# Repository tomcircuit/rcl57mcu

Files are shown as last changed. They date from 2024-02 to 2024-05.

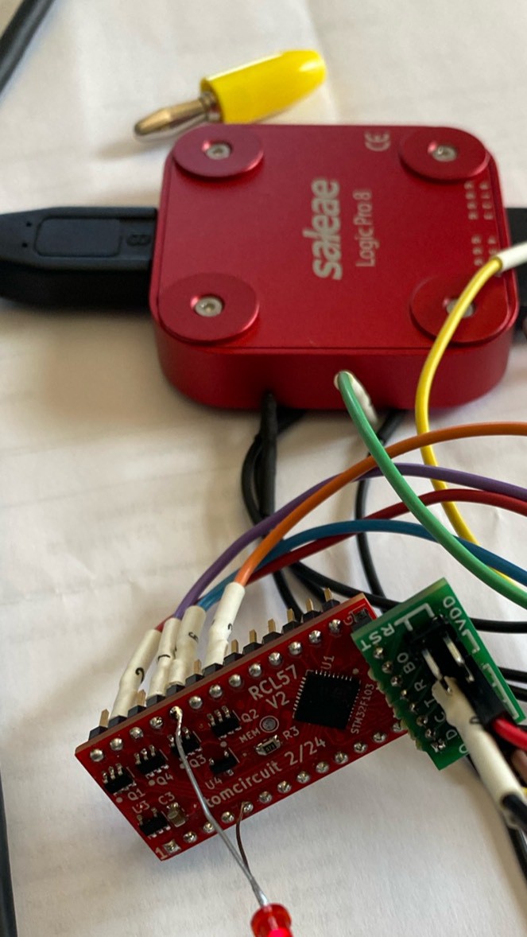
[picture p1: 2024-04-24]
media/assembled debug.jpg

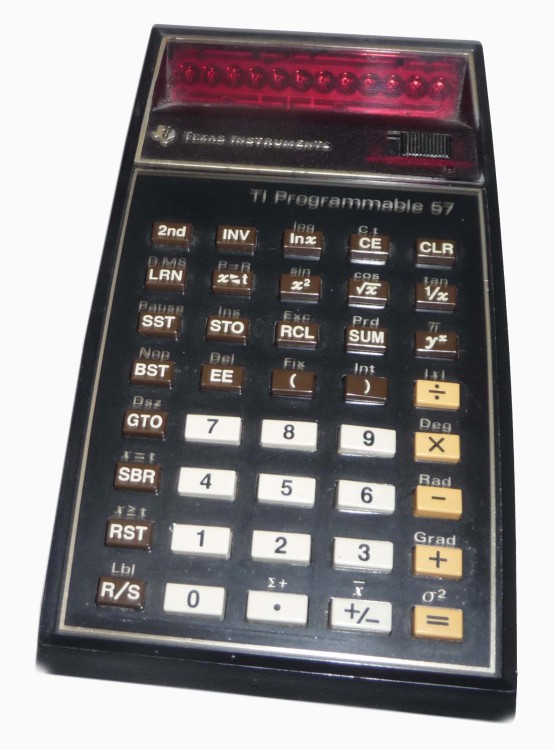
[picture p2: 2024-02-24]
media/ti57_image_uk_computing_history_museum.jpg

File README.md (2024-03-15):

# rcl57mcu

## MCU-based retrofit for TI-57 Programmable Calculators

This project came about because I stumbled across a TI-57 calculator with a "bad brain". The TMC1501 calculator-on-a-chip was faulty. This, in turn, led me to read more about this particular calculator and how the CPU inside functions. 

Fortunately, I am 'standing on the shoulders of giants' here - three people that have been of great help to me are Joerg Woerner, Jeff Parsons and Paul Novaes. All have humored me by answering my emails and helping me understand how the hardware works. 

Joerg's DATAMATH pages are amazing reading, and in particular there is an excellent [overview of the TMC1501 calculator-on-a-chip IC](http://www.datamath.org/Chips/TMC1500.htm) used in the TI-57.

Jeff Parsons' TI-57 pages include an online emulator and lots of history on TI-57 development. Extremely helpful is his [collection and analysis of original Texas Instruments patents](https://www.pcjs.org/machines/ti/ti57/patents/) filed around the introduction of this calculator.

Both Jeff and Paul have created TI-57 emulators. Paul's is an iOS app, and Jeff's is browser-based. Both emulate the TMC1501 CPU innards, which in turn execute the original TI-57 ROM code. So it is a faithful 'emulation'.

Paul was kind enough to put his [iOS app code](https://github.com/n3times/rcl57) up on GitHub

The 'guts' of the TMC1500 emulation are all contained within the 'engine' folder, and written in very generic and portable C. I learned an awful lot from studying this code.

## The Quest

I began to hatch a scheme - could I put a modern microcontroller (MCU) to the task of emulating the 1970's TMC1501? Could this hardware emulator be then installed into my defunct TI-57 to make it live again, perhaps even better than before?

See the hackaday page for more info on this project: 

https://hackaday.io/project/194963-ti-57-programmable-calculator-hardware-retrofit

Tom LeMense
February 2024

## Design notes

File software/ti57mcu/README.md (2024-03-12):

# RCL57mcu - TI-57 emulator on an MCU

* Author: Tom LeMense 
* Toolchain: Keil uVision/MDK
* Target: STM32F103TB (CM3, 128K Flash, 20K RAM)
* Hardware: rcl57mcu PCB V2
* Repository: [github.com/tomcircuit/rcl57mcu](https://github.com/tomcircuit/rcl57mcu)
* Project Webpage: [hackaday.io/project/194963](https://hackaday.io/project/194963)

Rcl57mcu was inspired by the work of Jeff Parsons and Paul Novaes, from whose work developoing PC and iOS emulators I was able to study and then eventually develop a microcontroller-based TI-57 emulator. Also invaluable to me is the DATAMATH website, carefully maintained by Joerg Woerner, which contains a trove of information on all things TI calculator, but more specifically on [the TMC1501 IC inside the TI-57](http://www.datamath.org/Chips/TMC1500.htm). The rcl57mcu embedded software is more a less an embedded 'wrapper' around the "TI57 Engine" by Paul Novaes, which can be found in this repository: [github.com/n3times/rcl57](https://github.com/n3times/rcl57). 

Rcl57mcu is a hardware "drop-in" replacement for TI-57 TMC1500 DIP-28, and brings a few enhancements over the original:
 
- Calculation at 4x the speed of the original TI-57 
	+ display timing and PAUSE are same as original
- Non-volatile storage/retrieval of up to 20 user programs
- A "power save" mode if the keyboard is left idle
- USB micro-B rechargeable 3.7V LiPo battery 
- (tbc) Lower overall energy consumption

In theory, rcl57mcu could be used as speedup/retrofit in TI-55 and TI-42/"MBA" calculators, as they use the same TMC1500 IC. Of course, the correct ROM image would need to be used. I do not have these calculators, so I cannot say as to whether or not this actually works...

As part of the debugging activies, I used the "USART_Utilities" package from Saeid Yazdani, which I found at the following website [www.embedonix.com](http://www.embedonix.com) 

RCL57mcu hardware was designed by me, using the wonderful KiCAD 7.0 toolchain. Design files can be found at the GitHub repository.

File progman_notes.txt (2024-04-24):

 From TI patent, the ORDER of the segment activation
 7,6,5,2,4,0,1,3
 (don't really care about this so much I don't think)
 
Segment numbering:
E, F, B, G, C, A, D, P
0  1  2  3  4  5  6  7  (WVU)

This makes the keyboard mapping sane, also, as the segment # is then the row #

   1  1  1        
   2  1  0  9  8  7  6  5  4  3  2  1
   
      L. #  #     C  C  C  C         	These are the "library" flash programs   21-99
   
      U. #  #     C  C  C  C				These are the "user" EEPROM programs   01-20

		 ## is program number
		 CCCC is CRC-16 of program (or "- - - -" if blank)

+ increase #
- decrease #	  
STO store program in slot # if it's a USER slot (1-20)
RCL recall program from slot #
GTO goto L.21
RST goto U.01
CE clear program in slot # if it's a USER slot (1-20)
R/S exit program manager

Keep the same 50us tick:

Enter with slot = 01

generate_display_data

display_cycle

check_keyboard_input

10-100KHz
100us to 10us
DATA 0 ---> MARK/SPACE
DATA 1 ---> SPACE/MARK
MAK == DATA 1
NoMAK == DATA 0
SAK == DATA 1
NoSAK = CV (MARK-MARK)

STANDBY PULSE (TSTBY #9) = HIGH for 600us minimum (!!!)
START HEADER SETUP TIME (TSS #10) = 10us minimum (can do this instead of STANDBY pulse)
START HEADER LOW PULSE TIME (THDR #11) = 5us minimum (follows standby/header pulse)

START HEADER = 0x55 + MAK 

MEMIO high for TSS, then MEMIO low for THDR, then 0x55, then MAK, then NoSAK (don't check SAK)

24MHz clock to APB1
TIM3 :

RCC->APB1ENR |= RCC_APB1ENR_TIM3EN

TIM3->PSC = 24-1; // 24MHz APB1 divide-by-24 = 1MHz = 1us per tick
TIM3->ARR = ticks-1;  // number of ticks to count up
TIM3->EGR = 0x0001;   // update event
TIM3->CR1 = 0x0009;	 // enable counting     but also set: OPM (b3 = 1 to count only once), 

NVIC->ISER[TIM3_IRQn >> 0x05] = (uint32_t)0x01 << (TIM3_IRQn & (uint8_t)0x1f); enable interrupts
TIM3->DIER = 0x0001; enable interrupts

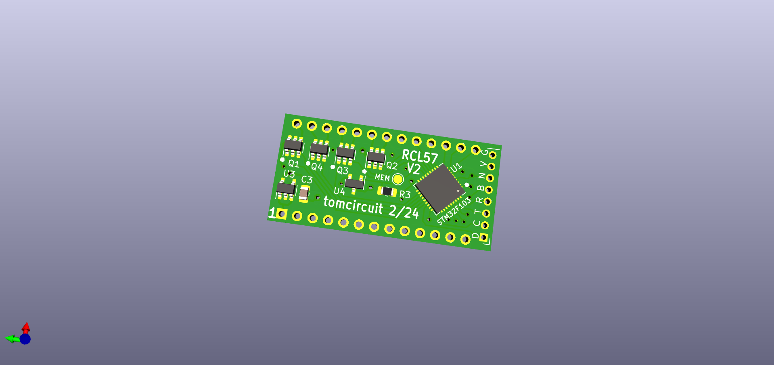
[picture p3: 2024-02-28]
hardware/rcl57_mcu/release/fab02/ti57mcu_v2_top3d.png

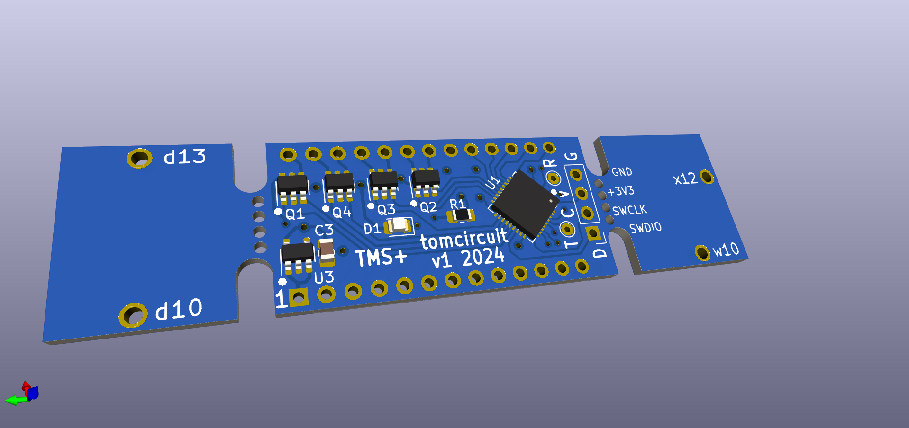
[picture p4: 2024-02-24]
hardware/rcl57_mcu/release/fab01/ti57mcu_top3d.png

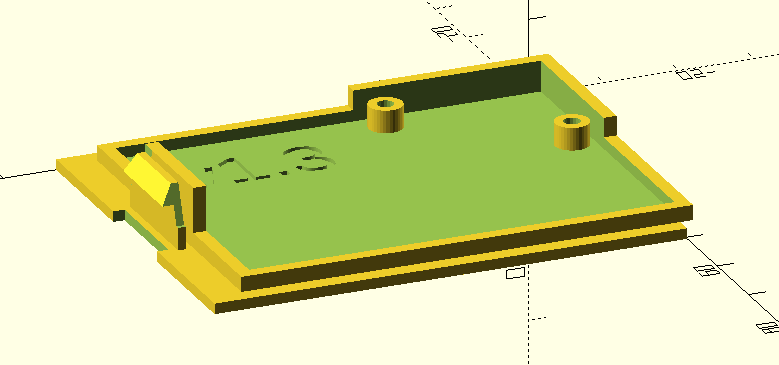
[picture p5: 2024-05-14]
mechanical/TI-57_LiPo_lid_1v3.png

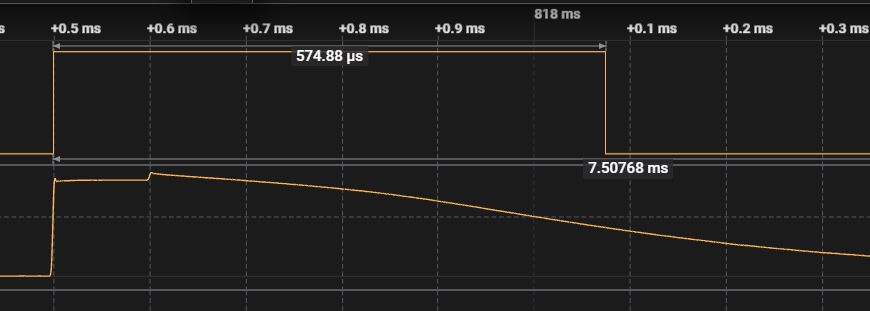
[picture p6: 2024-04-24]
media/short_segment_pulse.png

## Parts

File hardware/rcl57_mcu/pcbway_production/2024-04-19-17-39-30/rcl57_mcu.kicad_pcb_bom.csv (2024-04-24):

designator | quantity | value | pack | mpn | mount_type
C1, C2, C4, C5 | 4 | 100nF | C_0805_2012Metric |  | smt
C3, C6 | 2 | 4.7uF | C_0805_2012Metric |  | smt
J1 | 1 | TMC1500 p1-13 | PinHeader_1x13_P2.54mm_Vertical |  | tht
J2 | 1 | TMC1500 p28-16 | PinHeader_1x13_P2.54mm_Vertical |  | tht
J3 | 1 | STLINK | PinHeader_1x08_P2.00mm_Vertical |  | tht
Q1, Q2, Q3, Q4 | 4 | DMP2240UDM-7 | SOT-23-6 |  | smt
R1 | 1 | 2K | R_0805_2012Metric_Pad1.20x1.40mm_HandSolder |  | smt
R3 | 1 | 47K | R_0805_2012Metric_Pad1.20x1.40mm_HandSolder |  | smt
R4 | 1 | 330 | R_0805_2012Metric_Pad1.20x1.40mm_HandSolder |  | smt
RN1 | 1 | YC158TJR-072KL | R_Array_Convex_5x0603 |  | smt
U1 | 1 | STM32F103TBUx | QFN-36-1EP_6x6mm_P0.5mm_EP4.1x4.1mm |  | smt
U2 | 1 | TLC5929PWP | TSSOP-24-1EP_4.4x7.8mm_P0.65mm_EP3.2x5mm |  | smt
U3 | 1 | TLV70033_SOT23-5 | SOT-23-5 |  | smt
U4 | 1 | 11AA080/TT | SOT-23 |  | smt

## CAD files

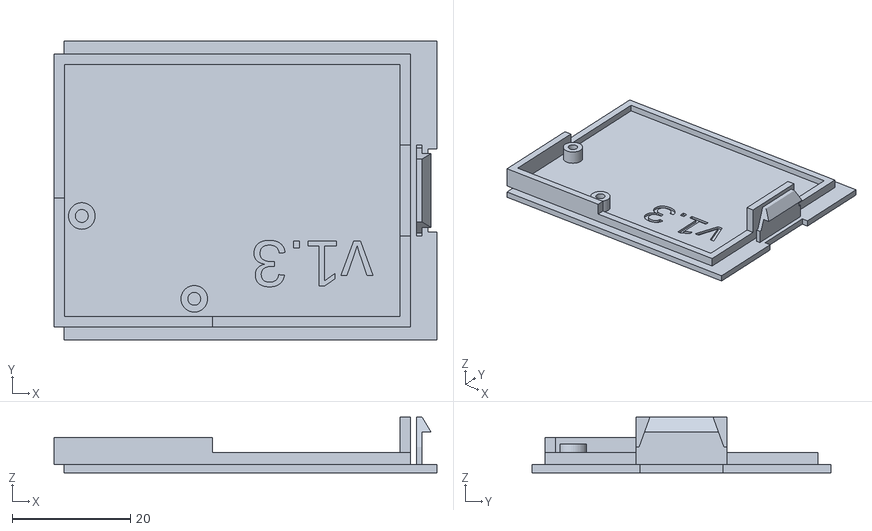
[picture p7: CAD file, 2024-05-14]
mechanical/TI-57_LiPo_lid_1v3.stl
64.7 x 50.5 x 9.40

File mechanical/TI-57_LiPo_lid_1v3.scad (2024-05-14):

/*
  TI-57 Battery Lid for LiPo Pack V1.3
  This is intended to hold a PCB and a LiPo battery for RCL-57.

  Dimensions measured from a TI-57 and a TI-55 calculator, and several BP-7 packs.
  
  1.0 - high-walls - awful latch geometry
  1.1 - high-walls - still bad latch geometery
  1.2 - ref'd off of thingiverse "Majestic_line_battery_cover.stl" file - better...
  1.3 - increased latch tab Z, decreased latch spring wall thickness - much better!

  T. LeMense
  May 13, 2024
*/


$fa = 1;
$fs = 0.4;

// W is width, and is along X AXIS
// L is length, and is along Y AXIS
// H is height, and is along Z AXIS
// T is thickness, and is along either X or Y AXIS 

// baseplate (first surface)
base_w = 63;  
base_l = 50.5;   
base_h = 1.4;  

/*
// Majestic Line Battery Cover reference STL
translate([base_w/2,base_l/2,0])
rotate([0,0,270])
import("C:/Users/lemenset/Personal/TI57_upgrade/mechanical/Majestic_line_Battery_cover.stl");
//*/

// "ledges" are setbacks around perimeter of base
ledge_long_edge = 2.2;  // ledge along long sides (estimated)
ledge_short_edge = 1.7; // ledge step-back along non-latch short end
latch_setback = 3.5;  // setback of latch (measured)
ledge_latch_edge = 4.5;  // setback of latch-side wall (measured)

// "superstructure" box - around entire cavity
super_w = base_w - ledge_latch_edge + ledge_short_edge; // width (long edge)
super_l = base_l - ledge_long_edge - ledge_long_edge;  // length (short edge)
super_h = 2;        // height of superstructure box
super_wall_t = 1.75;     // superstructure wall thickness
super_floor_add_h = 0.5; // additional floor thickness

echo("superstructure inside width is", super_w-2*super_wall_t);
echo("superstructure inside length is", super_l-2*super_wall_t);

// PCB information
pcb_l = 25;
pcb_w = 20;
pcb_t = 1.6;
pcb_hole_from_edge = 3;

// PCB position w.r.t. lid
pcb_x = 0;
pcb_y = ledge_long_edge + super_wall_t;
pcb_comp_z = 6; 
pcb_solder_z = pcb_comp_z-pcb_t-base_h;

// latch 'tab' is an extruded 2D polygon
latch_tab_w1 = 2.5; // "thickest" part of latch feature
latch_tab_h = 2.5;  // "height" of latch tab
latch_tab_w2 = 1;   // "thinnest" part of latch tab
latch_tab_l = 16.0; // "length" of latch tab
latch_tab_z = 5.5;   // relative to base_h

// construct latch tab polygon point set
p0 = [0, 0];
p1 = [0, latch_tab_h];
p2 = [latch_tab_w2,latch_tab_h];
p3 = [latch_tab_w1,0];
tab_points = [p0, p1, p2, p3];

// hinge cutout is extruded 2D polygon
cutout_l = 10.0;
cutout_h = latch_tab_z;

// built hinge cutout polygon point set
p4 = [0, 0];
p5 = [0, cutout_h];
p6 = [(latch_tab_l - cutout_l)/2,cutout_h];
p7 = [latch_tab_w2,0];
cutout_points = [p4, p5, p6, p7];

module RoundedBoss(side,height,hole_dia){
    difference() {
        translate([0,0,0])
        cylinder(d=side,h=height);
        
        translate([0,0,height/3])
        cylinder(d=hole_dia,h=height/1.5);
    }
}

function RoundedBossHoleCenter(side,height,hole_dia) = [side/2,side/2,0];   

//location of the PCB mounting bosses
boss_l = 4.5;
boss_h_dia = 2.2;
boss_inset = (boss_l - boss_h_dia)/4;
h1 = [pcb_x+pcb_hole_from_edge,pcb_y+pcb_w-pcb_hole_from_edge,0];
h2 = h1 + [pcb_l-2*pcb_hole_from_edge,-pcb_w+2*pcb_hole_from_edge,0];

// build the lid using additive and subtractive items
union(){
    difference() {
        union() {        
        // additive items        
            
        // the baseplate
        cube(size=[base_w, base_l, base_h]);
            
        // the superstructure volume
        translate([-ledge_short_edge, ledge_long_edge, base_h])
            cube([super_w, super_l,super_h]); 
        
        // the PCB box volume
        translate([-ledge_short_edge, ledge_long_edge, base_h])
            cube([super_wall_t+pcb_l,super_wall_t+pcb_w,pcb_comp_z-base_h]);
    
        // the locking tab
        translate([base_w - latch_setback,ledge_long_edge+(super_l/2)+(latch_tab_l/2),latch_tab_z+base_h]) 
            rotate([90,0,0]) 
                linear_extrude(height=latch_tab_l) polygon(tab_points);
    
        // the locking tab spring wall
        translate([base_w - latch_setback,ledge_long_edge+(super_l/3),base_h])
            cube([1, super_l/3, latch_tab_z]);
        
        // the locking tab "backstop"
        translate([base_w - ledge_latch_edge-super_wall_t,ledge_long_edge+(super_l/3),base_h])
            cube([super_wall_t,super_l/3, latch_tab_z+latch_tab_h]);
    
        } //union
        
        // subtractive items                    
        // remove tab release slot from base
        translate([base_w - 1.5,(base_l/2)-((latch_tab_l-2)/2),-0.25]) 
            cube([2.5,(latch_tab_l-2),2]);
            
        // remove the two hinge cutouts
        translate([base_w-ledge_latch_edge,ledge_long_edge+(super_l/2)-(latch_tab_l/2)-0.15,base_h+3])
            rotate([90,0,90])
                linear_extrude(height=3*super_wall_t)
                    polygon(cutout_points);
        
        translate([super_w+ledge_latch_edge,ledge_long_edge+(super_l/2)+(latch_tab_l/2)+0.15,base_h+3])
            rotate([90,0,-90]) 
                linear_extrude(height=3*super_wall_t) 
                    polygon(cutout_points);        
    
        // flatten the rounded wall edges
        translate([-2, 1.25+super_wall_t, base_h+12.5])
            cube([5,super_l-2*super_wall_t,5]);
        translate([base_w-4, 1.25+super_wall_t, base_h+10])
            cube([5,super_l-2*super_wall_t,5]);
    
        // remove the superstructure insides
        translate([super_wall_t-ledge_short_edge, ledge_long_edge+super_wall_t, base_h+super_floor_add_h])
            cube([super_w-2*super_wall_t, super_l-2*super_wall_t, 20]); 
        
        // etch some text into the floor
        translate([2*base_w/3,base_l/3,base_h])
            rotate([0,0,180])
                linear_extrude(3)
                    text( "v1.3", size= 8, ,halign = "center", valign = "bottom" );
    } //difference
    // objects located inside the superstructure cavity
    
    // PCB mounting screw bosses   
    translate(h1 + [0,0,base_h+super_floor_add_h])
        RoundedBoss(boss_l,pcb_solder_z,boss_h_dia);  // for #2 screw

    translate(h2 + [0,0,base_h+super_floor_add_h])
        RoundedBoss(boss_l,pcb_solder_z,boss_h_dia);  // for #2 screw    

} //union

/*
// uncomment this block if a pcb "model" is desired
pcb_model_z = pcb_solder_z+base_h;
hole_dia = 0.086 * 25.4;

translate([0,0,pcb_model_z]) 
    color("green") 
    linear_extrude(height=pcb_t) 
    difference(){
       translate ([pcb_x,pcb_y,0]) square ([pcb_l,pcb_w],false); 
       translate(h1) circle(d = hole_dia);
       translate(h2) circle(d = hole_dia);
    }
//*/

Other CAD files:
software/ti57console/output/rcl57.obj
software/ti57console/output/leds57.obj
software/ti57console/output/ti57.obj
software/ti57console/output/mux57.obj
software/ti57console/output/utils57.obj
software/ti57console/output/logger57.obj
software/ti57console/output/rom57.obj
software/ti57console/output/lrn57.obj
software/ti57console/output/key57.obj
software/ti57console/output/state57.obj
software/ti57console/output/app_ti57.obj
software/ti57console/output/log57.obj

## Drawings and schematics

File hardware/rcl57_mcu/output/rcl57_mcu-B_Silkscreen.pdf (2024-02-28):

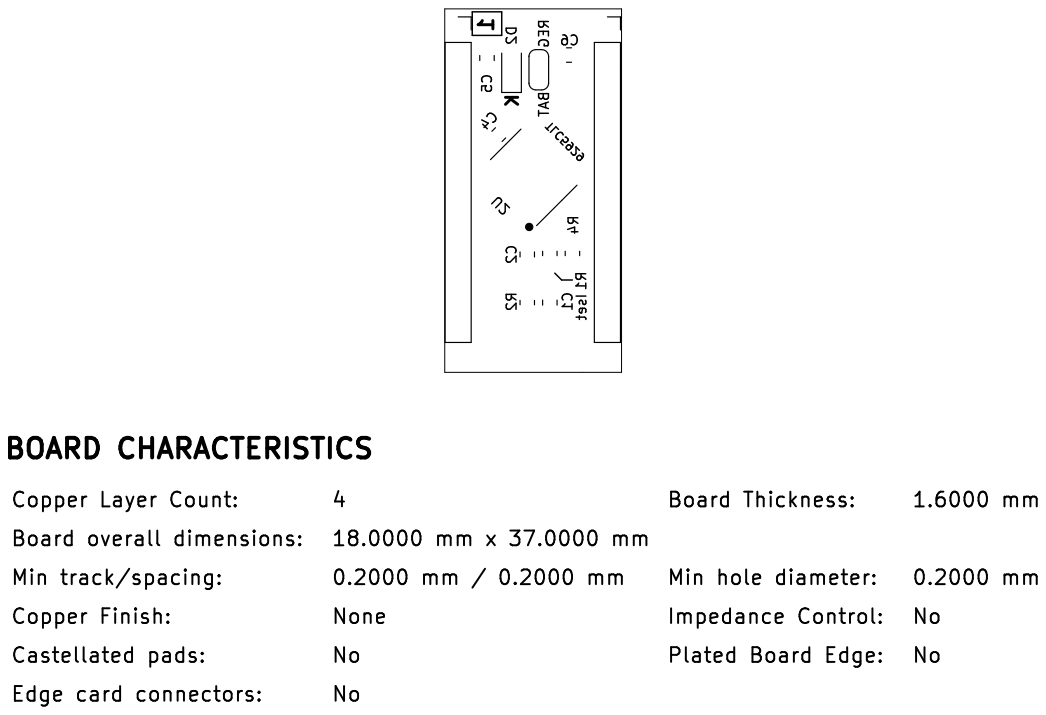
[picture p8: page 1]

TLC5929 C1 Copper Finish: Min track/spacing: 0.2000 mm

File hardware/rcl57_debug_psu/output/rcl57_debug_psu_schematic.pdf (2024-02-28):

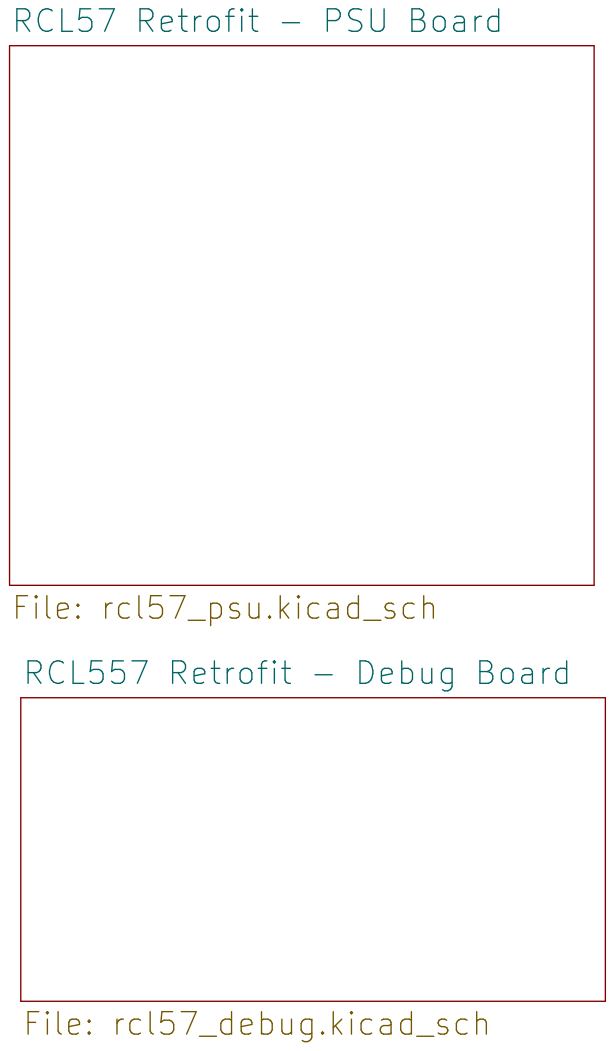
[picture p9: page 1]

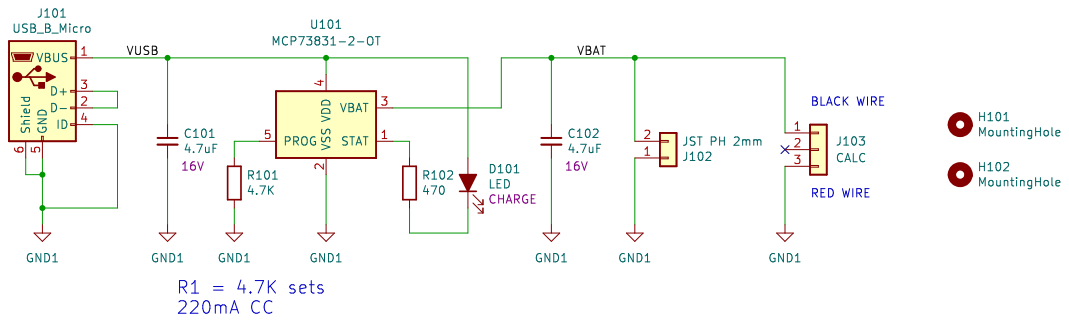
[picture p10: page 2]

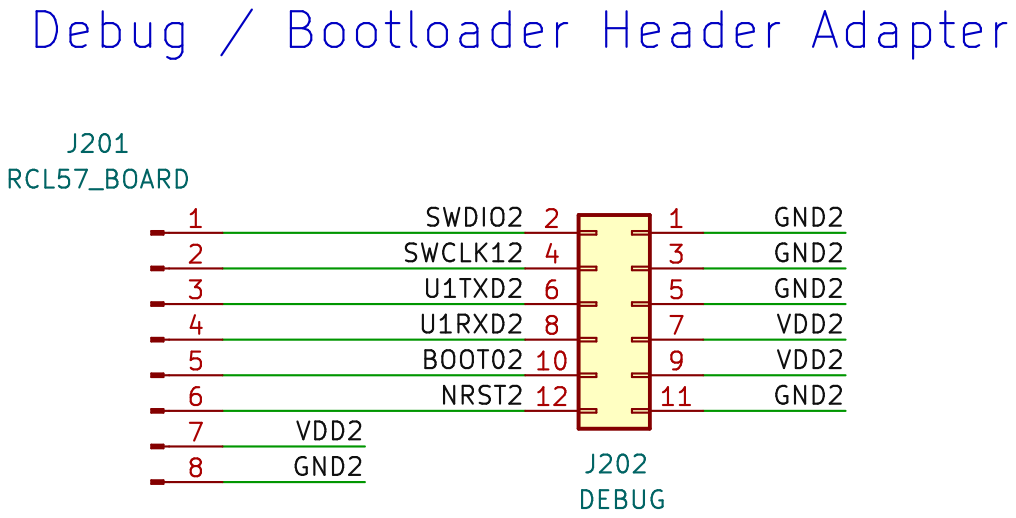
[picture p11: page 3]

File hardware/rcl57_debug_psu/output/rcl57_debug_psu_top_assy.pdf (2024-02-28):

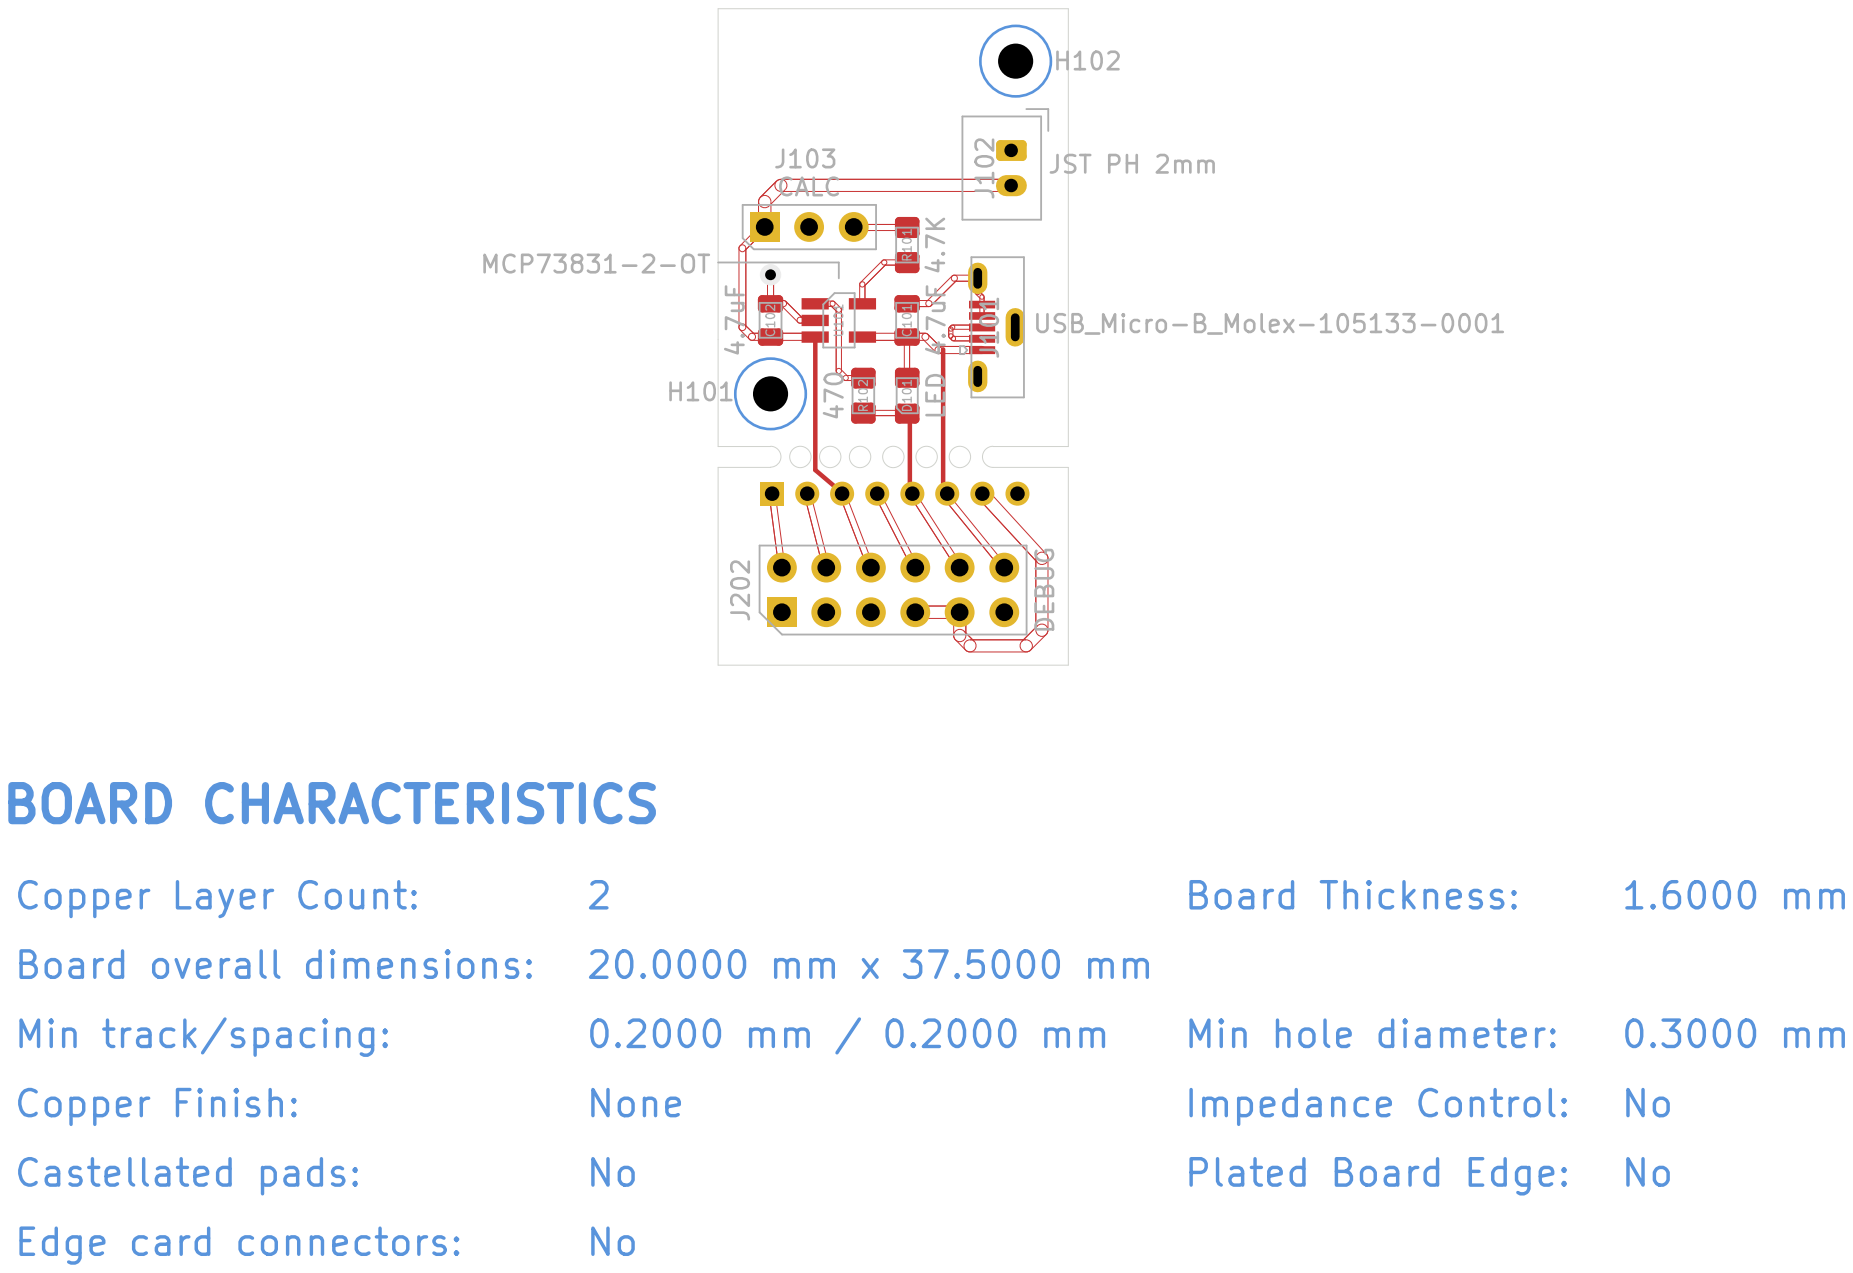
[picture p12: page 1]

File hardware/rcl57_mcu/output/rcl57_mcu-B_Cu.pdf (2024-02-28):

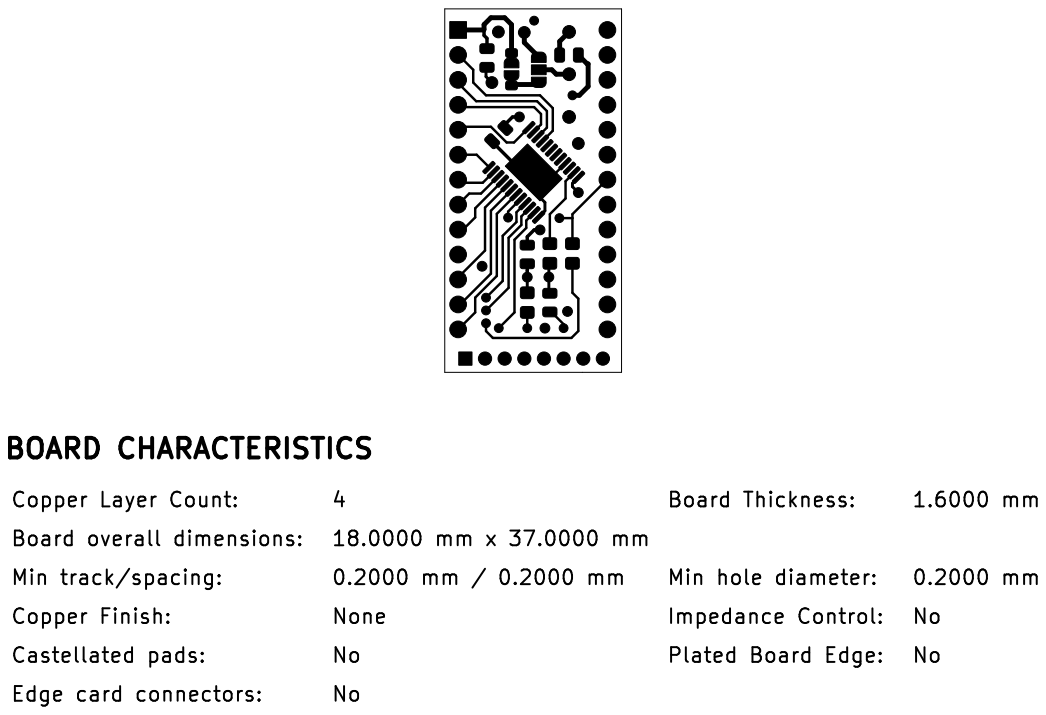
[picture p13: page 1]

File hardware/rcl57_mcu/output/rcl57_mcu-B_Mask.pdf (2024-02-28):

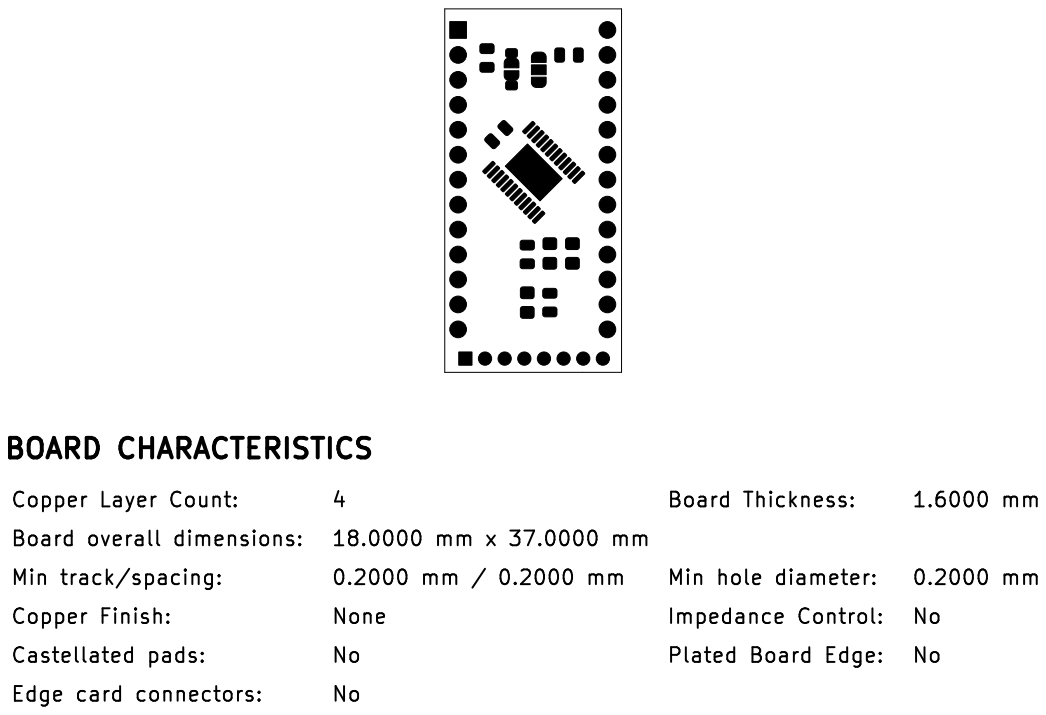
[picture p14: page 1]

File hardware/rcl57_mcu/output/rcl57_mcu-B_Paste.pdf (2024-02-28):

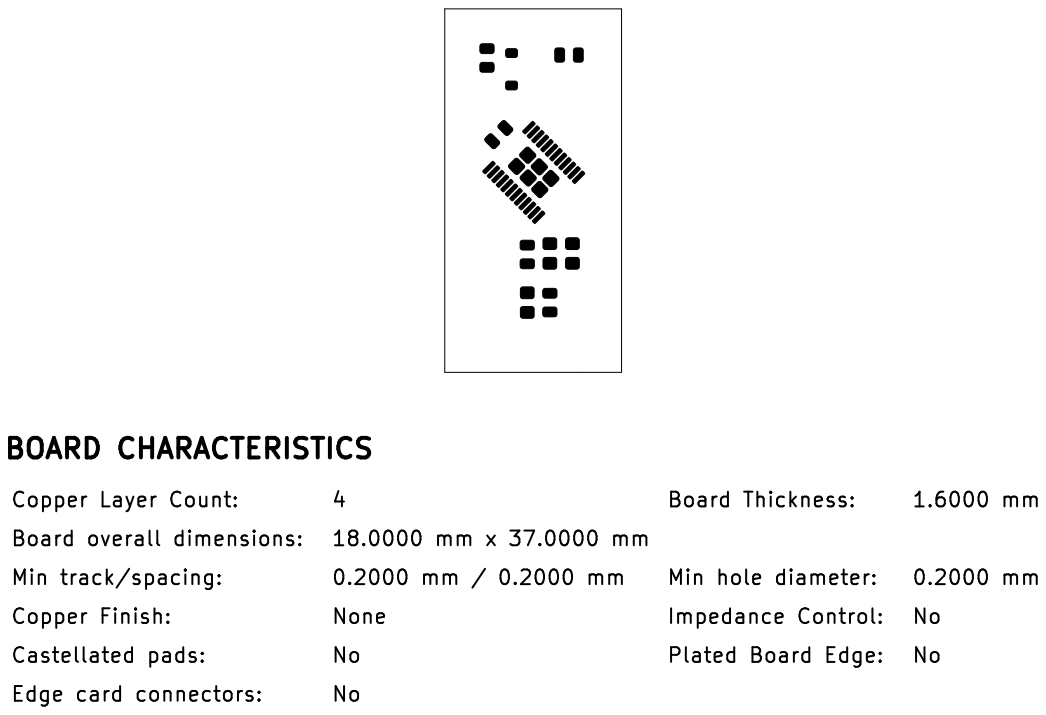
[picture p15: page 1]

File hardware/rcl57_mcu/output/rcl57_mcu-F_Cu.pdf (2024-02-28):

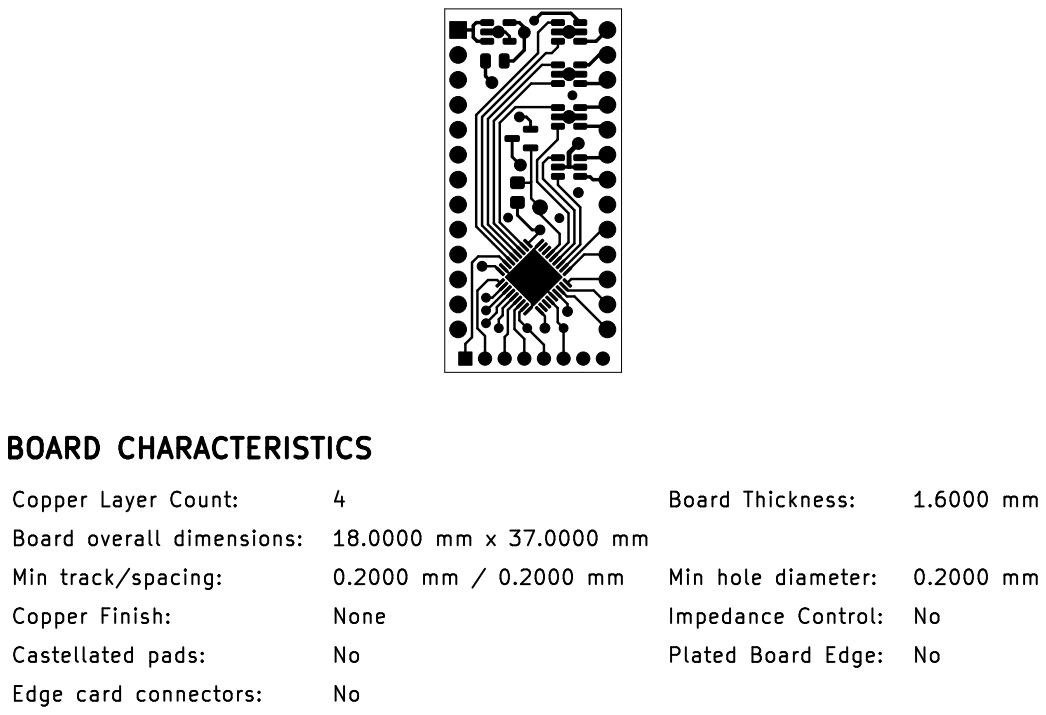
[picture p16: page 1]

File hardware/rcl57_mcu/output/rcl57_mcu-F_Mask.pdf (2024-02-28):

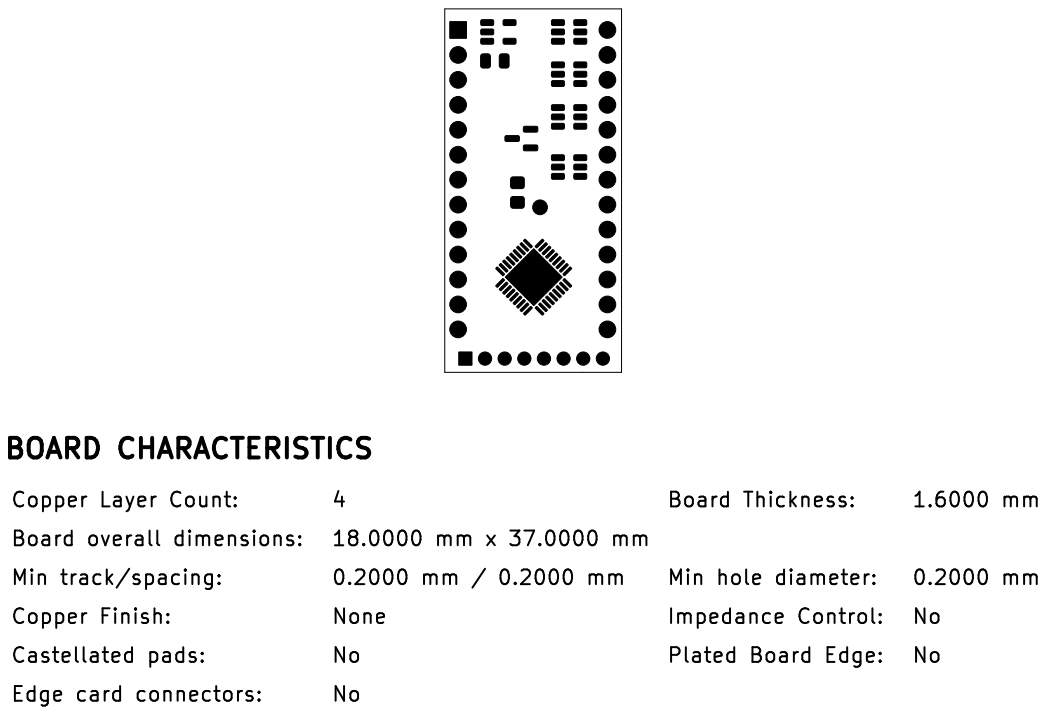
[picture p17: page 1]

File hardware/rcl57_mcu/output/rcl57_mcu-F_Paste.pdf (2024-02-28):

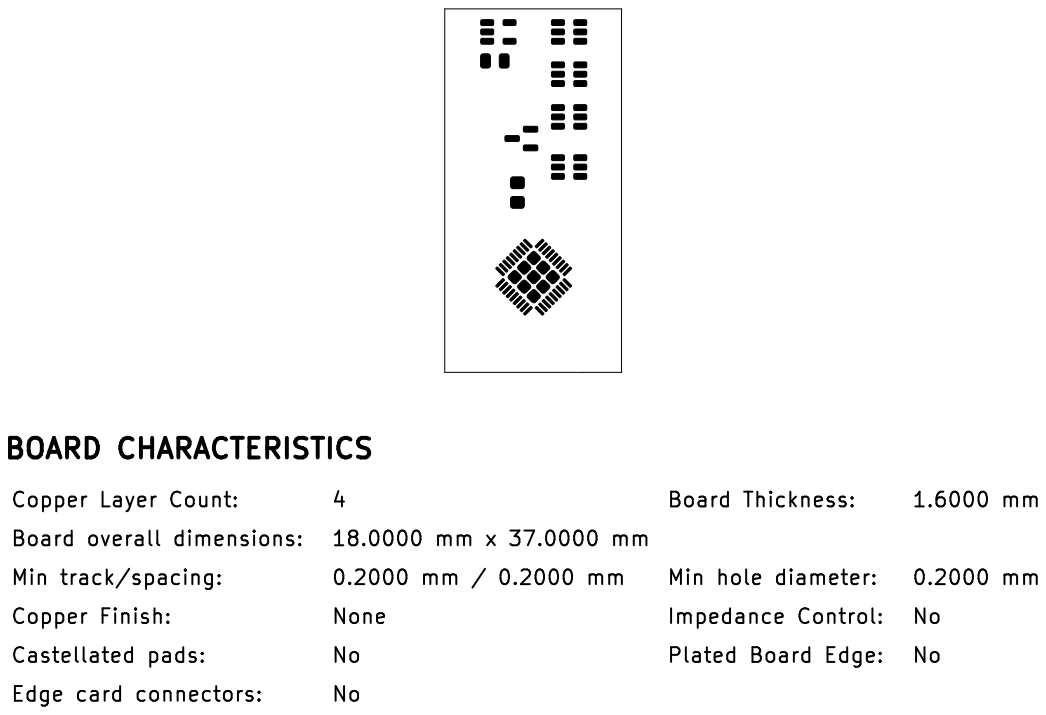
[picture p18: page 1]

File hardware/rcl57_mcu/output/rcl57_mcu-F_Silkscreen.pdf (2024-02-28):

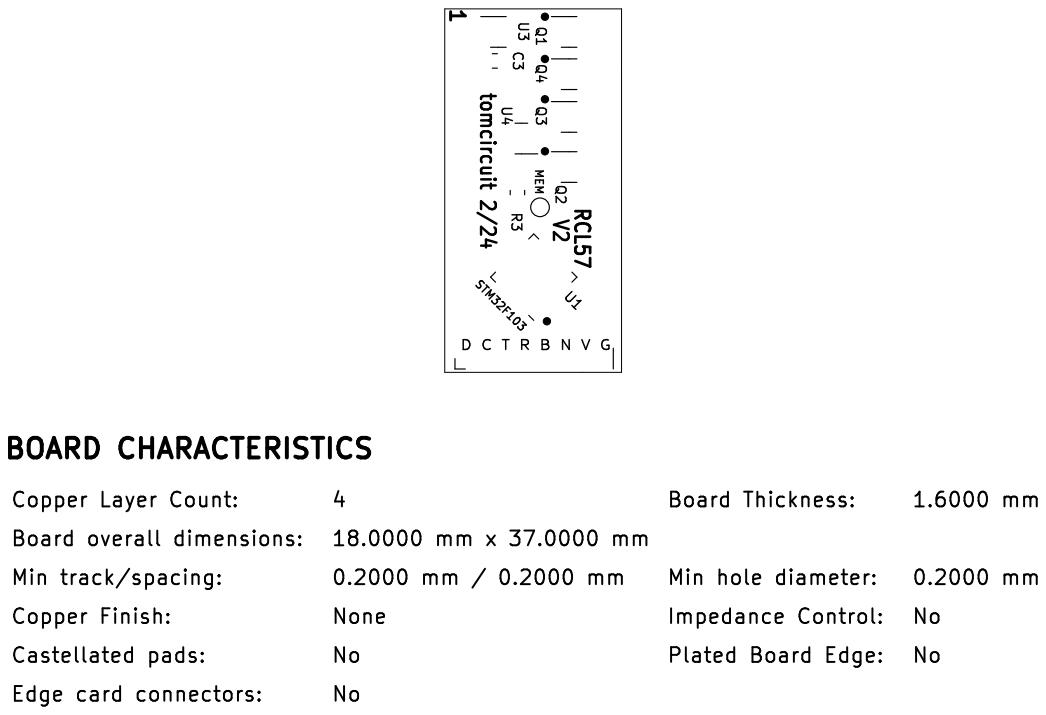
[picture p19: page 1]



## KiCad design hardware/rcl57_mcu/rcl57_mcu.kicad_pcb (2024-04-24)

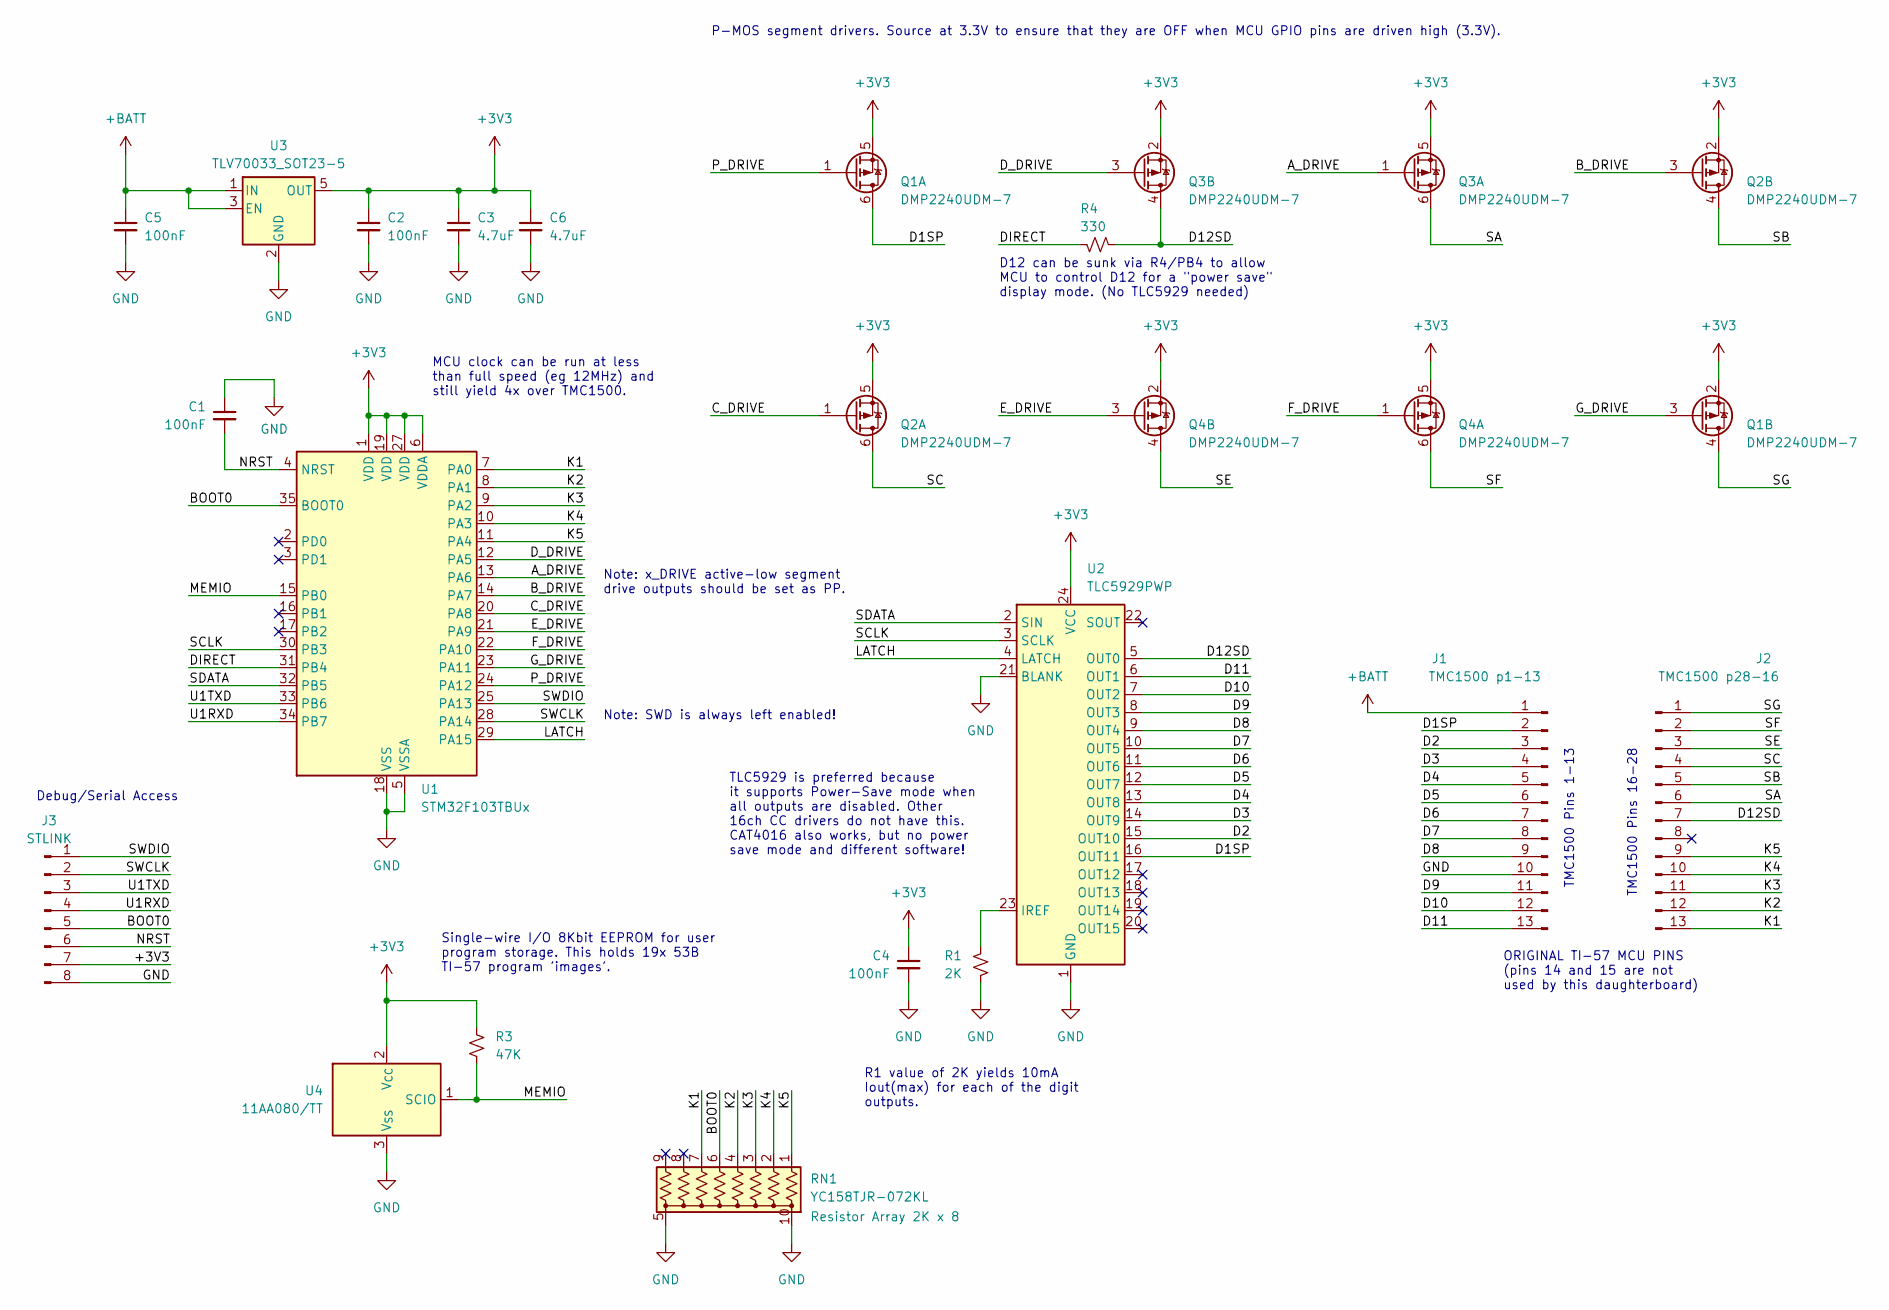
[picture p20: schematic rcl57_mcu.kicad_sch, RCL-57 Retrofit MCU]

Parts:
C1, C2, C4, C5: 100nF; C_0805_2012Metric
C3, C6: 4.7uF; C_0805_2012Metric
J1: TMC1500 p1-13; PinHeader_1x13_P2.54mm_Vertical
J2: TMC1500 p28-16; PinHeader_1x13_P2.54mm_Vertical
J3: STLINK; PinHeader_1x08_P2.00mm_Vertical
Q1, Q2, Q3, Q4: DMP2240UDM-7; SOT-23-6
R1: 2K; R_0805_2012Metric_Pad1.20x1.40mm_HandSolder
R3: 47K; R_0805_2012Metric_Pad1.20x1.40mm_HandSolder
R4: 330; R_0805_2012Metric_Pad1.20x1.40mm_HandSolder
RN1: YC158TJR-072KL; R_Array_Convex_5x0603
U1: STM32F103TBUx; QFN-36-1EP_6x6mm_P0.5mm_EP4.1x4.1mm
U2: TLC5929PWP; TSSOP-24-1EP_4.4x7.8mm_P0.65mm_EP3.2x5mm
U3: TLV70033_SOT23-5; SOT-23-5
U4: 11AA080/TT; SOT-23

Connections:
+3V3: C2.1, C3.1, C4.1, C6.1, J3.7, Q1.2 (SB), Q1.5 (SA), Q2.2 (SB), Q2.5 (SA), Q3.2 (SB), Q3.5 (SA), Q4.2 (SB), Q4.5 (SA), R3.1, U1.1 (VDD), U1.6 (VDDA), U1.19 (VDD), U1.27 (VDD), U2.24 (VCC), U3.5 (OUT), U4.2 (V_{CC})
+BATT: C5.1, J1.1, U3.1 (IN), U3.3 (EN)
/A_DRIVE: Q3.1 (GA), U1.13 (PA6)
/BOOT0: J3.5, RN1.6 (R5), U1.35 (BOOT0)
/B_DRIVE: Q2.3 (GB), U1.14 (PA7)
/C_DRIVE: Q2.1 (GA), U1.20 (PA8)
/D1SP: J1.2, Q1.6 (DA), U2.16 (OUT11)
/D2: J1.3, U2.15 (OUT10)
/D3: J1.4, U2.14 (OUT9)
/D4: J1.5, U2.13 (OUT8)
/D5: J1.6, U2.12 (OUT7)
/D6: J1.7, U2.11 (OUT6)
/D7: J1.8, U2.10 (OUT5)
/D8: J1.9, U2.9 (OUT4)
/D9: J1.11, U2.8 (OUT3)
/D10: J1.12, U2.7 (OUT2)
/D11: J1.13, U2.6 (OUT1)
/D12SD: J2.7, Q3.4 (DB), R4.1, U2.5 (OUT0)
/DIRECT: R4.2, U1.31 (PB4)
/D_DRIVE: Q3.3 (GB), U1.12 (PA5)
/E_DRIVE: Q4.3 (GB), U1.21 (PA9)
/F_DRIVE: Q4.1 (GA), U1.22 (PA10)
/G_DRIVE: Q1.3 (GB), U1.23 (PA11)
/K1: J2.13, RN1.7 (R6), U1.7 (PA0)
/K2: J2.12, RN1.4 (R4), U1.8 (PA1)
/K3: J2.11, RN1.3 (R3), U1.9 (PA2)
/K4: J2.10, RN1.2 (R2), U1.10 (PA3)
/K5: J2.9, RN1.1 (R1), U1.11 (PA4)
/LATCH: U1.29 (PA15), U2.4 (LATCH)
/MEMIO: R3.2, U1.15 (PB0), U4.1 (SCIO)
/NRST: C1.2, J3.6, U1.4 (NRST)
/P_DRIVE: Q1.1 (GA), U1.24 (PA12)
/SA: J2.6, Q3.6 (DA)
/SB: J2.5, Q2.4 (DB)
/SC: J2.4, Q2.6 (DA)
/SCLK: U1.30 (PB3), U2.3 (SCLK)
/SDATA: U1.32 (PB5), U2.2 (SIN)
/SE: J2.3, Q4.4 (DB)
/SF: J2.2, Q4.6 (DA)
/SG: J2.1, Q1.4 (DB)
/SWCLK: J3.2, U1.28 (PA14)
/SWDIO: J3.1, U1.25 (PA13)
/U1RXD: J3.4, U1.34 (PB7)
/U1TXD: J3.3, U1.33 (PB6)
GND: C1.1, C2.2, C3.2, C4.2, C5.2, C6.2, J1.10, J3.8, R1.2, RN1.5 (common1), RN1.10 (common2), U1.5 (VSSA), U1.18 (VSS), U1.26 (VSS), U1.36 (VSS), U1.37 (VSS), U2.1 (GND), U2.21 (BLANK), U2.25 (GND), U3.2 (GND), U3.4 (NC), U4.3 (V_{SS})
unnamed: R1.1, U2.23 (IREF)

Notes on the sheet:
TLC5929 is preferred because it supports Power-Save mode when all outputs are disabled. Other 16ch CC drivers do not have this. CAT4016 also works, but no power save mode and different software!
Single-wire I/O 8Kbit EEPROM for user program storage. This holds 19x 53B TI-57 program 'images'.
Note: SWD is always left enabled!
D12 can be sunk via R4/PB4 to allow MCU to control D12 for a "power save" display mode. (No TLC5929 needed)
TMC1500 Pins 1-13
ORIGINAL TI-57 MCU PINS (pins 14 and 15 are not used by this daughterboard)
P-MOS segment drivers. Source at 3.3V to ensure that they are OFF when MCU GPIO pins are driven high (3.3V).
R1 value of 2K yields 10mA Iout(max) for each of the digit outputs.
TMC1500 Pins 16-28
Debug/Serial Access
MCU clock can be run at less than full speed (eg 12MHz) and still yield 4x over TMC1500.
Note: x_DRIVE active-low segment drive outputs should be set as PP.

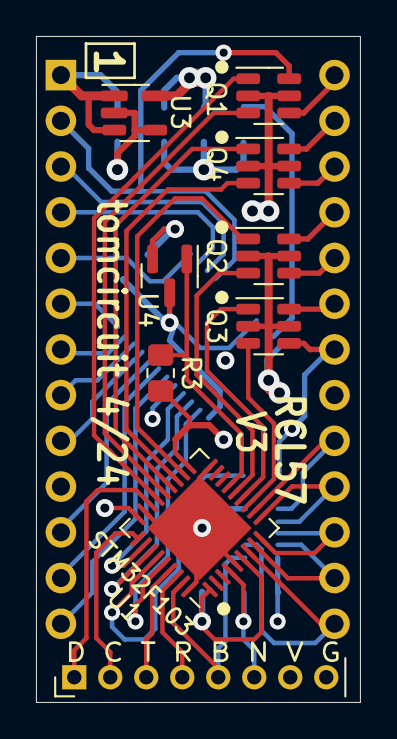
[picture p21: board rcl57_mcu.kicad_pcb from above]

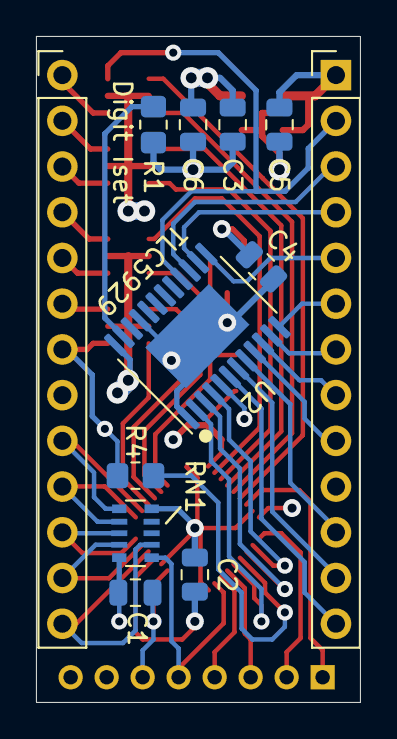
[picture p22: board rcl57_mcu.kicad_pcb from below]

Board: 4 copper layers, 18.0 x 37.0 mm, 21 parts (12 on the bottom side), 46 nets.

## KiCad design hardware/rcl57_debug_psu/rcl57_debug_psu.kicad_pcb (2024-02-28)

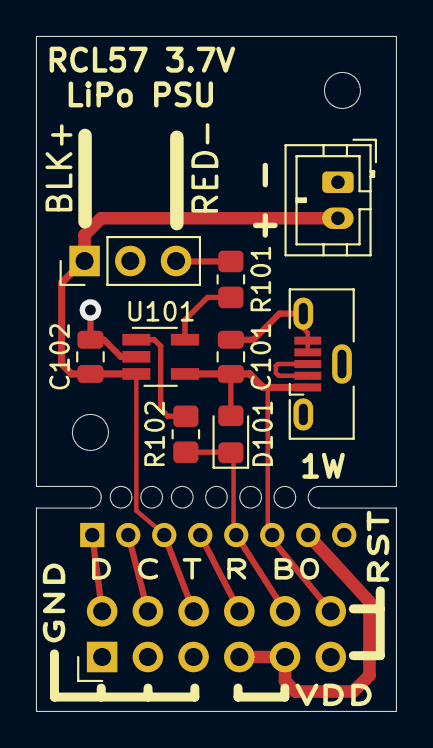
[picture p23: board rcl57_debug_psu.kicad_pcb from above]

Board: 2 copper layers, 20.0 x 37.5 mm, 13 parts (1 on the bottom side), 15 nets.

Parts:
C101, C102: 4.7uF; C_0805_2012Metric
D101: LED; LED_0805_2012Metric_Pad1.15x1.40mm_HandSolder
H101, H102: MountingHole; MountingHole_2mm
J101: USB_Micro-B_Molex-105133-0001
J102: JST PH 2mm; JST_PH_B2B-PH-K_1x02_P2.00mm_Vertical
J103: CALC; PinHeader_1x03_P2.54mm_Vertical
J201: RCL57_BOARD; PinSocket_1x08_P2.00mm_Vertical
J202: DEBUG; PinHeader_2x06_P2.54mm_Vertical
R101: 4.7K; R_0805_2012Metric_Pad1.20x1.40mm_HandSolder
R102: 470; R_0805_2012Metric_Pad1.20x1.40mm_HandSolder
U101: MCP73831-2-OT; SOT-23-5_HandSoldering

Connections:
/RCL57 Retrofit - PSU Board/VBAT: C102.1, J102.2, J103.1, U101.3 (VBAT)
/RCL57 Retrofit - PSU Board/VUSB: C101.1, D101.2 (A), J101.1 (VBUS), U101.4 (VDD)
/RCL557 Retrofit - Debug Board/BOOT02: J201.5, J202.10
/RCL557 Retrofit - Debug Board/GND2: J201.8, J202.1, J202.3, J202.5, J202.11
/RCL557 Retrofit - Debug Board/NRST2: J201.6, J202.12
/RCL557 Retrofit - Debug Board/SWCLK12: J201.2, J202.4
/RCL557 Retrofit - Debug Board/SWDIO2: J201.1, J202.2
/RCL557 Retrofit - Debug Board/U1RXD2: J201.4, J202.8
/RCL557 Retrofit - Debug Board/U1TXD2: J201.3, J202.6
/RCL557 Retrofit - Debug Board/VDD2: J201.7, J202.7, J202.9
GND1: C101.2, C102.2, J101.4 (ID), J101.5 (GND), J101.6 (Shield), J102.1, J103.3, R101.2, U101.2 (VSS)
unnamed: D101.1 (K), R102.2
unnamed: J101.2 (D-), J101.3 (D+)
unnamed: R101.1, U101.5 (PROG)
unnamed: R102.1, U101.1 (STAT)

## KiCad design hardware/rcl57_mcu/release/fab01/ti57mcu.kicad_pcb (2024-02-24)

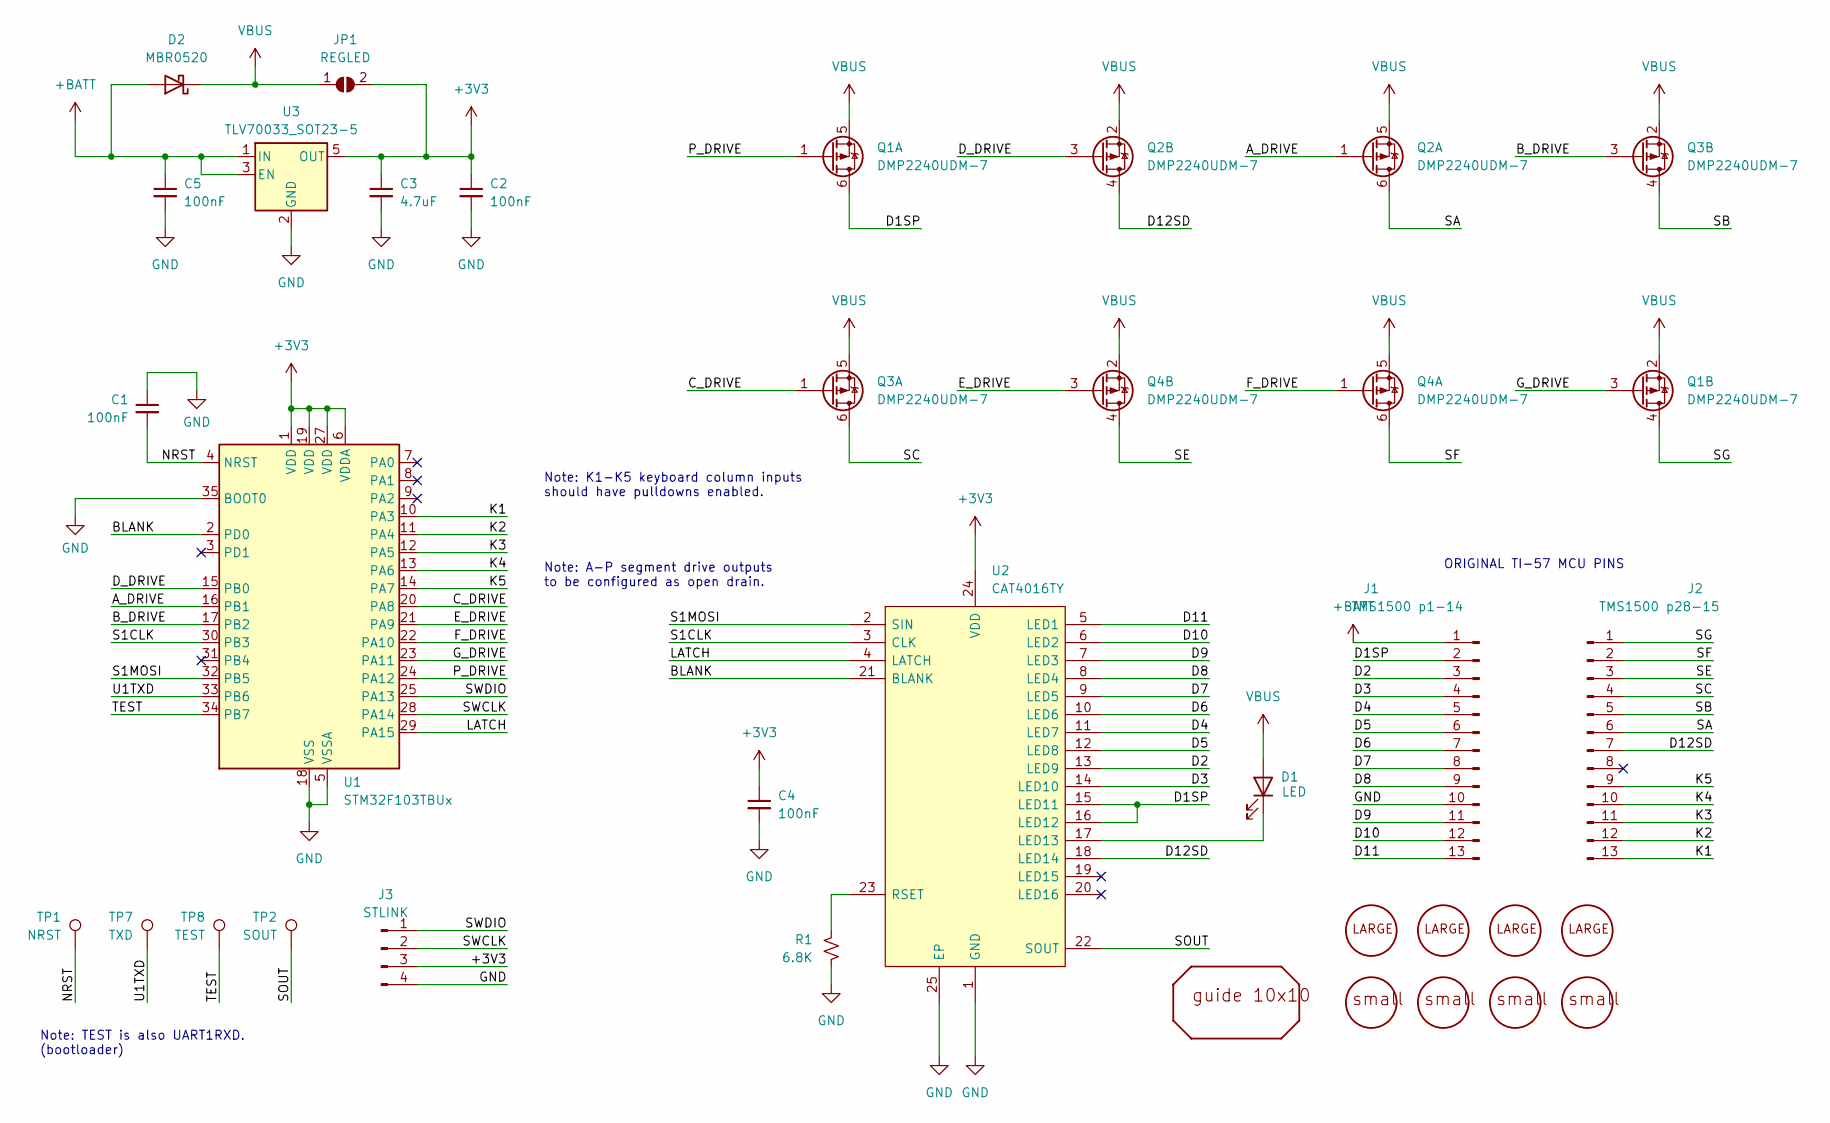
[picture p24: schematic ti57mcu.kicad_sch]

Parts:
C1, C2, C4, C5: 100nF; C_0805_2012Metric
C3: 4.7uF; C_0805_2012Metric
D1: LED; LED_0805_2012Metric
D2: MBR0520; D_SOD-123
J1: TMS1500 p1-14; PinHeader_1x13_P2.54mm_Vertical
J2: TMS1500 p28-15; PinHeader_1x13_P2.54mm_Vertical
J3: STLINK; PinHeader_1x04_P2.54mm_Vertical
JP1: REGLED; SolderJumper-2_P1.3mm_Open_RoundedPad1.0x1.5mm
Q1, Q2, Q3, Q4: DMP2240UDM-7; SOT-23-6
R1: 6.8K; R_0805_2012Metric_Pad1.20x1.40mm_HandSolder
TP1: NRST; TestPoint_Pad_D1.5mm
TP2: SOUT; TestPoint_Pad_D1.5mm
TP7: TXD; TestPoint_THTPad_D1.5mm_Drill0.7mm
TP8: TEST; TestPoint_THTPad_D1.5mm_Drill0.7mm
U1: STM32F103TBUx; QFN-36-1EP_6x6mm_P0.5mm_EP4.1x4.1mm
U2: CAT4016TY; TSSOP-24_4.4x7.8mm_P0.65mm; Mouser Part Number 698-CAT4016HV6-GT2
U3: TLV70033_SOT23-5; SOT-23-5
U91, U92, U93, U94: PIN_SMALL_SINGLE_DEVICE; PIN_SMALL_SINGLE
U95, U96, U97, U98: PIN_LARGE_SINGLE_DEVICE; PIN_LARGE_SINGLE_NOSILK
U99: GUIDE_10X10; BOARD_10X10_USERCMTS

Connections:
+3V3: C2.1, C3.1, C4.1, J3.3, JP1.2 (B), U1.1 (VDD), U1.6 (VDDA), U1.19 (VDD), U1.27 (VDD), U2.24 (VDD), U3.5 (OUT)
+BATT: C5.1, D2.2 (A), J1.1, U3.1 (IN), U3.3 (EN)
/A_DRIVE: Q2.1 (GA), U1.16 (PB1)
/BLANK: U1.2 (PD0), U2.21 (BLANK)
/B_DRIVE: Q3.3 (GB), U1.17 (PB2)
/C_DRIVE: Q3.1 (GA), U1.20 (PA8)
/D1SP: J1.2, Q1.6 (DA), U2.15 (LED11), U2.16 (LED12)
/D2: J1.3, U2.13 (LED9)
/D3: J1.4, U2.14 (LED10)
/D4: J1.5, U2.11 (LED7)
/D5: J1.6, U2.12 (LED8)
/D6: J1.7, U2.10 (LED6)
/D7: J1.8, U2.9 (LED5)
/D8: J1.9, U2.8 (LED4)
/D9: J1.11, U2.7 (LED3)
/D10: J1.12, U2.6 (LED2)
/D11: J1.13, U2.5 (LED1)
/D12SD: J2.7, Q2.4 (DB), U2.18 (LED14)
/D_DRIVE: Q2.3 (GB), U1.15 (PB0)
/E_DRIVE: Q4.3 (GB), U1.21 (PA9)
/F_DRIVE: Q4.1 (GA), U1.22 (PA10)
/G_DRIVE: Q1.3 (GB), U1.23 (PA11)
/K1: J2.13, U1.10 (PA3)
/K2: J2.12, U1.11 (PA4)
/K3: J2.11, U1.12 (PA5)
/K4: J2.10, U1.13 (PA6)
/K5: J2.9, U1.14 (PA7)
/LATCH: U1.29 (PA15), U2.4 (LATCH)
/NRST: C1.2, TP1.1, U1.4 (NRST)
/P_DRIVE: Q1.1 (GA), U1.24 (PA12)
/S1CLK: U1.30 (PB3), U2.3 (CLK)
/S1MOSI: U1.32 (PB5), U2.2 (SIN)
/SA: J2.6, Q2.6 (DA)
/SB: J2.5, Q3.4 (DB)
/SC: J2.4, Q3.6 (DA)
/SE: J2.3, Q4.4 (DB)
/SF: J2.2, Q4.6 (DA)
/SG: J2.1, Q1.4 (DB)
/SOUT: TP2.1, U2.22 (SOUT)
/SWCLK: J3.2, U1.28 (PA14)
/SWDIO: J3.1, U1.25 (PA13)
/TEST: TP8.1, U1.34 (PB7)
/U1TXD: TP7.1, U1.33 (PB6)
GND: C1.1, C2.2, C3.2, C4.2, C5.2, J1.10, J3.4, R1.2, U1.5 (VSSA), U1.18 (VSS), U1.26 (VSS), U1.35 (BOOT0), U1.36 (VSS), U1.37 (VSS), U2.1 (GND), U2.25 (EP), U3.2 (GND), U3.4 (NC)
unnamed: D1.1 (K), U2.17 (LED13)
unnamed: R1.1, U2.23 (RSET)
VBUS: D1.2 (A), D2.1 (K), JP1.1 (A), Q1.2 (SB), Q1.5 (SA), Q2.2 (SB), Q2.5 (SA), Q3.2 (SB), Q3.5 (SA), Q4.2 (SB), Q4.5 (SA)

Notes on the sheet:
ORIGINAL TI-57 MCU PINS
Note: A-P segment drive outputs to be configured as open drain.
Note: TEST is also UART1RXD. (bootloader)
Note: K1-K5 keyboard column inputs should have pulldowns enabled.

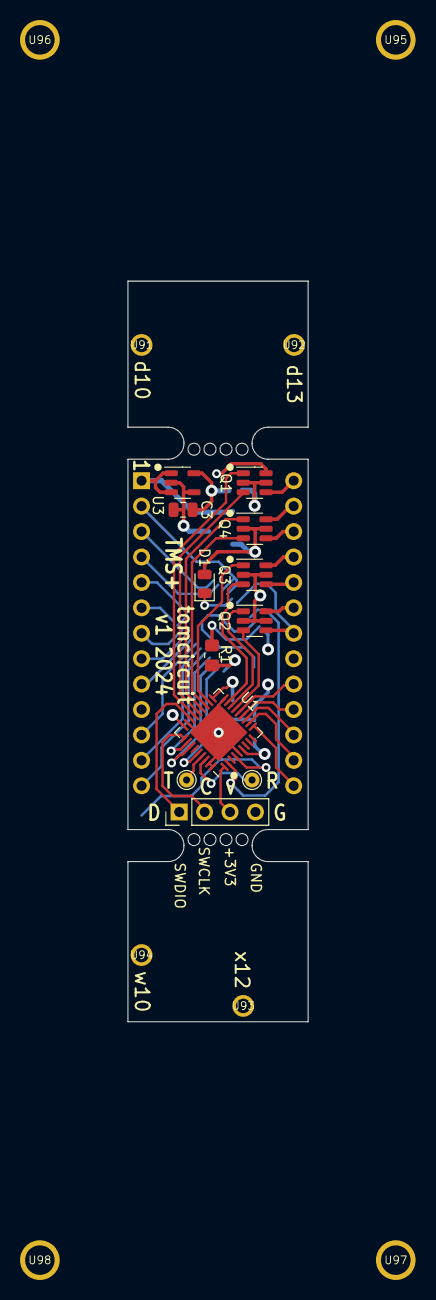
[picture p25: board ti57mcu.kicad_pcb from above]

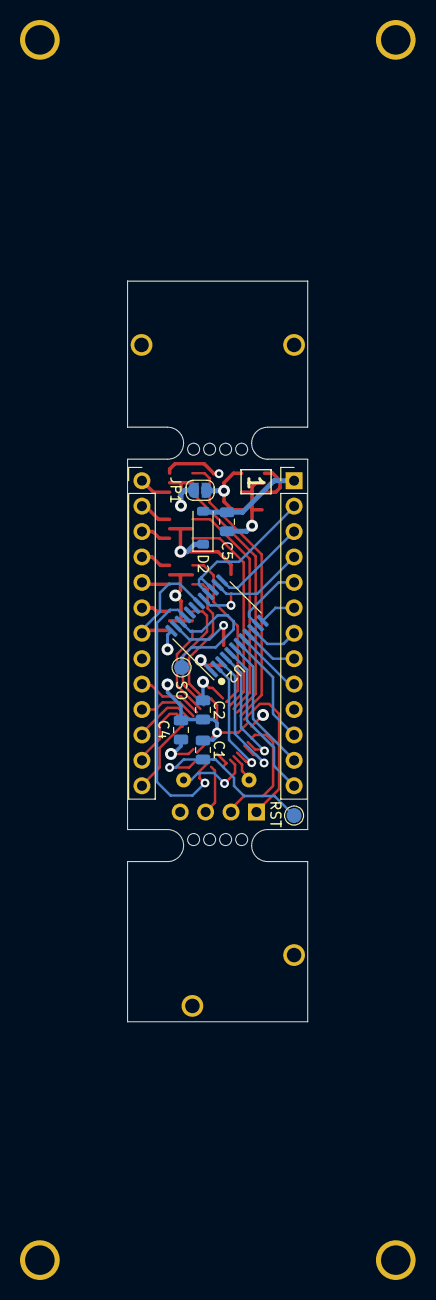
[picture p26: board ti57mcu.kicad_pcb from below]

Board: 4 copper layers, 18.0 x 74.0 mm, 32 parts (11 on the bottom side), 47 nets.

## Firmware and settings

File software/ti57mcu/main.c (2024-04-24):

/* Copyright (C) 2024 by Tom LeMense <https:github.com/tomcircuit>

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
THE SOFTWARE IS PROVIDED "AS IS", WITHOUT WARRANTY OF ANY KIND,
EXPRESS OR IMPLIED, INCLUDING BUT NOT LIMITED TO THE WARRANTIES OF
MERCHANTABILITY, FITNESS FOR A PARTICULAR PURPOSE AND
NONINFRINGEMENT. IN NO EVENT SHALL THE AUTHORS OR COPYRIGHT HOLDERS BE
LIABLE FOR ANY CLAIM, DAMAGES OR OTHER LIABILITY, WHETHER IN AN ACTION
OF CONTRACT, TORT OR OTHERWISE, ARISING FROM, OUT OF OR IN CONNECTION
WITH THE SOFTWARE OR THE USE OR OTHER DEALINGS IN THE SOFTWARE.  */

#include "stm32f10x.h"
#include "ti57.h"
#include "rcl57mcu.h"
#include "mux57.h"
#include "addon57.h"

/* Target: STM32F103TBU6 at 24 MHz on RCL57 V2 PCB */
/* https://hackaday.io/project/194963 */

/* STM32F103 peripheral initialization prototypes*/
void InitGPIO();
void InitUSART();
void InitSysTick();
void InitTIM3();
void InitSPI();
void InitADC();

/* SysTick interrupt handler & Delay function */
void SysTick_Handler(void);
void Delay(__IO uint32_t nTime);

/* globals */
static __IO uint32_t TimingDelay;   // Delay() function counter
shadow_status_t ee_status_shadow;   // RAM copy of EEPROM status block

/* varoius strings for 'splash' displays and USART messages */
#ifdef TI57_ROM
    const uint8_t str_version[] = " RCL57 v0.1 ";
    const uint8_t str_splash[] =  "   RCL-57   ";
#endif
#ifdef TI55_ROM
    const uint8_t str_version[] = " RCL55 v0.1 ";
    const uint8_t str_splash[] =  "   RCL-55   ";
#endif
const uint8_t str_ee_fail[] = "   EE FAIL  ";

/////////////

/* this function sets SYSCLK = HCLK = APB1 = APB2 = HSI/2 * 6 = 24 MHz */
/* it also sets flash access to 0WS and enables the CPU prefetch buffer */
void SystemCoreClockConfigure(void)
{

    RCC->CR |= ((uint32_t)RCC_CR_HSION);                     // Enable HSI
    while ((RCC->CR & RCC_CR_HSIRDY) == 0);                  // Wait for HSI Ready

    RCC->CFGR = RCC_CFGR_SW_HSI;                             // HSI is system clock
    while ((RCC->CFGR & RCC_CFGR_SWS) != RCC_CFGR_SWS_HSI);  // Wait for HSI used as system clock

    FLASH->ACR  = FLASH_ACR_PRFTBE;                          // Enable Prefetch Buffer
    FLASH->ACR &= ~FLASH_ACR_LATENCY;                                                // Flash 0 wait state
    FLASH->ACR |= FLASH_ACR_LATENCY_0;

    RCC->CFGR |= RCC_CFGR_HPRE_DIV1;                         // HCLK = SYSCLK
    RCC->CFGR |= RCC_CFGR_PPRE1_DIV1;                        // APB1 = HCLK
    RCC->CFGR |= RCC_CFGR_PPRE2_DIV1;                        // APB2 = HCLK

    RCC->CR &= ~RCC_CR_PLLON;                                // Disable PLL

    //  PLL configuration:  = HSI/2 * 6 = 24 MHz
    RCC->CFGR &= ~(RCC_CFGR_PLLSRC | RCC_CFGR_PLLXTPRE | RCC_CFGR_PLLMULL);
    RCC->CFGR |= (RCC_CFGR_PLLSRC_HSI_Div2 | RCC_CFGR_PLLMULL6);

    RCC->CR |= RCC_CR_PLLON;                                 // Enable PLL
    while ((RCC->CR & RCC_CR_PLLRDY) == 0)
        __NOP();           // Wait till PLL is ready

    RCC->CFGR &= ~RCC_CFGR_SW;                               // Select PLL as system clock source
    RCC->CFGR |=  RCC_CFGR_SW_PLL;
    while ((RCC->CFGR & RCC_CFGR_SWS) != RCC_CFGR_SWS_PLL);  // Wait till PLL is system clock src
}

int main()
{
    ti57_t ti57;
    uint8_t scancode = 0; // row/col of keypress; e.g. 2ND = 0x11 or 0x99 for ProgMan entry
    int16_t cycle_cost = 0;               // "cost" of instruction in terms of TMS1500 cycles (1 for all but DISP which is 32)
    uint32_t num_cycles = 0;     // total running cycles counter
    uint32_t idle_disp_cycles = 0;    // cycles elapsed since last keyboard activity

    bool rcode;        // boolean return code
    uint32_t temp_int;

    uint8_t codes[16], masks[16];

    /* initialize MCU clock tree to 24 MHz, 0WS, prefetch on */
    SystemCoreClockConfigure();
    SystemCoreClockUpdate();

    /* initialize MCU peripherals: GPIO, USART, SysTick, TIM3 */
    InitGPIO();
    InitUSART();
    InitSysTick();
    InitTIM3();
    InitSPI();
    InitADC();

    /* disable all segment driver outputs */
    hw_segment_disable_all();

    /* Initialize TCL5929 digit driver - all digits off, set brightness to 50% */
    hw_digit_driver_initialize();

    /* Disable the "Direct D12" output */
    DIRECT_D12_OFF;

    /* output a welcome string on USART */
    UU_PutString(USART1, str_version);

    /* Display a "splash screen" */
    mux57_splash(str_splash, 300);

    /* Load and validate the EEPROM status block */
    if (addon57_validate_status_block(ee_status_shadow) == false)
    {
        /* alert that EEPROM is not found/not accessible */
        mux57_splash(str_ee_fail, 300);
    }

    /* Set TCL5929 digit driver intensity to value from status shadow */
    hw_digit_driver_intensity(ee_status_shadow[EE_OFFSET_BRIGHT]);

    /* initialize TI-57 emulator */
    ti57_init(&ti57);

    while (1)
    {
        // DEBUG instruction duration tick on
        DEBUG_TICK_ON;

        /* execute the next TMC1500 instruction */
        cycle_cost = ti57_next(&ti57);
        num_cycles += cycle_cost;

        // DEBUG instruction duration tick off
        DEBUG_TICK_OFF;

        // DEBUG press the 1/x key after 18500 cycles
        //if (num_cycles > 18500 && num_cycles < 18600)
        //{
        //      ti57.is_key_pressed = true;
        //      ti57.col = 5;
        //      ti57.row = 2;       // this is 1/x which will cause error displey
        //}

        /* check if display action is required */
        if (ti57.display_update == true)
        {
            /* DEBUG dump the display to USART1 - this increases the display cycle duration!! */
            //UU_PutString(USART1, mux57_display_to_str(ti57.dA, ti57.dB));

            /* The TI-57 ROM always issues 2x DISP instructions due to
               original hardware limitations. Here, the first DISP will check
               the flag, which is not set, and then in this display update
               sequence the flag will be set/clear depending on K inputs. The
               second DISP will catch the flag and process it. */
            ti57.is_key_pressed = false;

            /* do the 6.4ms display cycle, collect keyboard scan codes */
            scancode = hw_display_cycle(ti57.dA, ti57.dB);

            /* increment the idle keyboard cycle counter if no keys detected */
            if (scancode == 0)
            {
                idle_disp_cycles += 1;
            }
            /* if any single keys were pressed during this display cycle,
               copy the keypress information into ti57 structure and let
                           the TI-57 emulation take care of what to do */
            else if (scancode < 0x8F)
            {
                /* DEBUG dump keypress row,col to UART */
                UU_PutChar(USART1, '#');
                UU_PutHexByte(USART1, scancode);

                /* copy row and column info to ti57 structure */
                ti57.row = scancode >> 4;
                ti57.col = scancode & 0x0F;
                ti57.is_key_pressed = true;

                /* clear the idle keyboard counter */
                idle_disp_cycles = 0;
            }
            /* if 2ND+INV+CLR is pressed, enter PROGRAM MANAGER */
            else if (scancode == SCANCODE_PROGMAN_ENTRY)
            {
                idle_disp_cycles = 0;       // clear the idle keyboard counter
                scancode = 0;
                //mode_progman();
            }
            else if (scancode == 0xFF)
                UU_PutString(USART1, ":ADCfault");

            /* has the keyboard been idle too long? if so, go to powersave */
            if (idle_disp_cycles > PSAVE_ENTRY_IDLE_DISP_CYCLES)
            {
                addon57_powersave();
                idle_disp_cycles = 0;       // clear the idle keyboard counter
                scancode = 0;
            }
        }

        /* wait for remainder of SysTick interval in SLEEP mode */
        __WFI();
    }
}


/* STM32F103 GPIO Initialization */
void InitGPIO()
{
    GPIO_InitTypeDef GPIO_InitStructure;

    /* GPIO are all on APB2 */
    RCC_APB2PeriphClockCmd(RCC_APB2Periph_GPIOC, ENABLE);
    RCC_APB2PeriphClockCmd(RCC_APB2Periph_GPIOB, ENABLE);
    RCC_APB2PeriphClockCmd(RCC_APB2Periph_GPIOA, ENABLE);

    /* enable the AFIO to allow remaps as well */
    RCC_APB2PeriphClockCmd(RCC_APB2Periph_AFIO, ENABLE);

    /* configure C13 and C14 as GPIO output pins */
    /* Blue Pill Debug pins! LED on C13 (0 = lit) */
    GPIO_InitStructure.GPIO_Pin = GPIO_Pin_13 | GPIO_Pin_14;
    GPIO_InitStructure.GPIO_Speed = GPIO_Speed_50MHz;
    GPIO_InitStructure.GPIO_Mode = GPIO_Mode_Out_PP;
    GPIO_Init(GPIOC, &GPIO_InitStructure);

    /* GPIO Configuration for RCL-57 Emulator PCB V2*/

    /* Configure PA0-PA4 as analog inputs */
    /* These are the K1,K2,K3,K4,K5 keypad column input lines */
    GPIO_InitStructure.GPIO_Pin = GPIO_Pin_0 | GPIO_Pin_1 | GPIO_Pin_2 | GPIO_Pin_3 | GPIO_Pin_4;
    GPIO_InitStructure.GPIO_Mode = GPIO_Mode_AIN;
    GPIO_Init(GPIOA, &GPIO_InitStructure);

    /* Configure PA5-12 as PP outputs*/
    /* These are the D,A,B,C,E,F,G,P segment control outputs --> init to 1 */
    GPIO_InitStructure.GPIO_Pin = GPIO_Pin_5 | GPIO_Pin_6 | GPIO_Pin_7 | GPIO_Pin_8
                                  | GPIO_Pin_9 | GPIO_Pin_10 | GPIO_Pin_11 | GPIO_Pin_12;
    GPIO_InitStructure.GPIO_Speed = GPIO_Speed_10MHz;
    GPIO_InitStructure.GPIO_Mode = GPIO_Mode_Out_PP;
    GPIO_Init(GPIOA, &GPIO_InitStructure);
    GPIO_SetBits(GPIOA, GPIO_Pin_5 | GPIO_Pin_6 | GPIO_Pin_7 | GPIO_Pin_8
                 | GPIO_Pin_9 | GPIO_Pin_10 | GPIO_Pin_11 | GPIO_Pin_12);

    /* configure A15 as GPIO output */
    /* This is TLC5925 LATCH control output --> init to 0 */
    GPIO_InitStructure.GPIO_Pin = GPIO_Pin_15;
    GPIO_InitStructure.GPIO_Speed = GPIO_Speed_10MHz;
    GPIO_InitStructure.GPIO_Mode = GPIO_Mode_Out_PP;
    GPIO_Init(GPIOA, &GPIO_InitStructure);

    /* Configure PB0 as OD GPIO */
    /* This is 11AA080 UNI/O signal input-output with 47K pullup */
    GPIO_InitStructure.GPIO_Pin = GPIO_Pin_0;
    GPIO_InitStructure.GPIO_Speed = GPIO_Speed_2MHz;
    GPIO_InitStructure.GPIO_Mode = GPIO_Mode_Out_OD;
    GPIO_Init(GPIOB, &GPIO_InitStructure);
    GPIO_ResetBits(GPIOB, GPIO_Pin_0);

    /* Configure PB4 as OD GPIO */
    /* This is a 'direct drive' for digit #12 cathode */
    GPIO_InitStructure.GPIO_Pin = GPIO_Pin_4;
    GPIO_InitStructure.GPIO_Speed = GPIO_Speed_2MHz;
    GPIO_InitStructure.GPIO_Mode = GPIO_Mode_Out_OD;
    GPIO_Init(GPIOB, &GPIO_InitStructure);
    GPIO_SetBits(GPIOB, GPIO_Pin_4);

    /* Configure PB3 and PB5 as PP GPIO */
    /* These are TLC5925 SCLK and SDATA outputs, respectively */
    /* Step 1 - disable JTAG interface (uses PB3) */
    GPIO_PinRemapConfig(GPIO_Remap_SWJ_JTAGDisable, ENABLE);
    /* Step 2 - Release PB3/TRACESWO and PB4/NJTRST from control of the
    debug port so they can be used as GPIO pins. This info was
    well-hidden in an ST forum posting. */
    DBGMCU->CR &= ~DBGMCU_CR_TRACE_IOEN;
    RCC->APB2ENR |= RCC_APB2ENR_AFIOEN;
    AFIO->MAPR |= AFIO_MAPR_SWJ_CFG_JTAGDISABLE;
    /* Step 3 - Enable SPI remap to RB3/RB5*/
    GPIO_PinRemapConfig(GPIO_Remap_SPI1, ENABLE);
    /* Step 4 - Configure PB3 and PB5 as AF GPIO */
    GPIO_InitStructure.GPIO_Pin = GPIO_Pin_3 | GPIO_Pin_5;
    GPIO_InitStructure.GPIO_Speed = GPIO_Speed_10MHz;
    GPIO_InitStructure.GPIO_Mode = GPIO_Mode_AF_PP;
    GPIO_Init(GPIOB, &GPIO_InitStructure);

    /* configure PB6 as USART1 TXD and PB7 as output */
    /* These are brought out to debug header on V2 PCB */
    /* configure PB6 as AF GPIO */
    GPIO_InitStructure.GPIO_Pin = GPIO_Pin_6;
    GPIO_InitStructure.GPIO_Speed = GPIO_Speed_10MHz;
    GPIO_InitStructure.GPIO_Mode = GPIO_Mode_AF_PP;
    GPIO_Init(GPIOB, &GPIO_InitStructure);
    /* Remap USART1 to PB6 */
    GPIO_PinRemapConfig(GPIO_Remap_USART1, ENABLE);

    /* configure PB7 as GPIO output */
    /* this could be USART1 RXD if needed */
    GPIO_InitStructure.GPIO_Pin = GPIO_Pin_7;
    GPIO_InitStructure.GPIO_Speed = GPIO_Speed_10MHz;
    GPIO_InitStructure.GPIO_Mode = GPIO_Mode_Out_PP;
    GPIO_Init(GPIOB, &GPIO_InitStructure);
}

/* STM32F103 USART1 initialization */
void InitUSART()
{
    USART_InitTypeDef USART_InitStructure;

    RCC_APB2PeriphClockCmd(RCC_APB2Periph_USART1, ENABLE);

    /* 230400 bps, 8N1, no flow control, TX only */
    USART_InitStructure.USART_BaudRate = 230400;
    USART_InitStructure.USART_WordLength = USART_WordLength_8b;
    USART_InitStructure.USART_StopBits = USART_StopBits_1;
    USART_InitStructure.USART_Parity = USART_Parity_No;
    USART_InitStructure.USART_HardwareFlowControl = USART_HardwareFlowControl_None;
    USART_InitStructure.USART_Mode = USART_Mode_Tx;

    USART_Init(USART1, &USART_InitStructure);
    USART_Cmd(USART1, ENABLE);
}

/* STM32F103 TIM3 Initialization */
void InitTIM3()
{
    TIM_TimeBaseInitTypeDef TimeBaseInitStructure;

    /* Enable the TIM3 clock.   */
    RCC_APB1PeriphClockCmd(RCC_APB1Periph_TIM3, ENABLE);

    /* De-init TIM3 to get it back to default values */
    TIM_DeInit(TIM3);

    /* Init the TimeBaseInitStructure with 1us/tick values */
    TimeBaseInitStructure.TIM_Prescaler = (SystemCoreClock / 1000000) - 1;
    TimeBaseInitStructure.TIM_CounterMode = TIM_CounterMode_Up;
    TimeBaseInitStructure.TIM_Period = 100;
    TIM_TimeBaseInit(TIM3, &TimeBaseInitStructure);
    TIM_SelectOnePulseMode(TIM3, TIM_OPMode_Single);
}

/* Initialize the STM32F103 SPI peripheral */
void InitSPI(void)
{
    SPI_InitTypeDef  SPI_InitStructure;

    /* enable the SPI1 peripheral clock */
    RCC_APB2PeriphClockCmd(RCC_APB2Periph_SPI1, ENABLE);

    /* Load SPI1 InitStructure with config options for CAT4016 */
    SPI_InitStructure.SPI_Direction = SPI_Direction_2Lines_FullDuplex;
    SPI_InitStructure.SPI_Mode = SPI_Mode_Master;

    /* 8-bit data word, MODE = 00, MSB first */
    SPI_InitStructure.SPI_DataSize = SPI_DataSize_8b;
    SPI_InitStructure.SPI_CPOL = SPI_CPOL_Low;
    SPI_InitStructure.SPI_CPHA = SPI_CPHA_1Edge;
    SPI_InitStructure.SPI_FirstBit = SPI_FirstBit_MSB;

    /* no hardware SS handling */
    SPI_InitStructure.SPI_NSS = SPI_NSS_Soft;

    /* SPI clock configuration APB2 clock / 8 */
    SPI_InitStructure.SPI_BaudRatePrescaler = SPI_BaudRatePrescaler_8;

    /* initialize and enable the SPI peripheral */
    SPI_Init(SPI1, &SPI_InitStructure);
    SPI_Cmd(SPI1, ENABLE);
}

void InitADC(void)
{
    ADC_InitTypeDef ADC_InitStructure;

    /* Enable the ADC clock.   */
    RCC_APB2PeriphClockCmd(RCC_APB2Periph_ADC1, ENABLE);

    /* Set the ADC clock prescalar to div-2 (12 MHz) */
    RCC_ADCCLKConfig(RCC_PCLK2_Div2);

    /* ADC1 configuration ------------------------------------------------------*/
    ADC_InitStructure.ADC_Mode = ADC_Mode_Independent;
    ADC_InitStructure.ADC_ScanConvMode = ENABLE;
    ADC_InitStructure.ADC_ContinuousConvMode = DISABLE;
    ADC_InitStructure.ADC_ExternalTrigConv = ADC_ExternalTrigConv_None;
    ADC_InitStructure.ADC_DataAlign = ADC_DataAlign_Right;
    ADC_InitStructure.ADC_NbrOfChannel = 1;
    ADC_Init(ADC1, &ADC_InitStructure);

    /* ADC1 regular channel 1 configuration */
    ADC_RegularChannelConfig(ADC1, ADC_Channel_0, 1, ADC_SampleTime_41Cycles5);

    /* Set injected sequencer length */
    ADC_InjectedSequencerLengthConfig(ADC1, 4);

    /* ADC1 injected channel Configuration */
    ADC_InjectedChannelConfig(ADC1, ADC_Channel_1, 1, ADC_SampleTime_41Cycles5);
    ADC_InjectedChannelConfig(ADC1, ADC_Channel_2, 2, ADC_SampleTime_41Cycles5);
    ADC_InjectedChannelConfig(ADC1, ADC_Channel_3, 3, ADC_SampleTime_41Cycles5);
    ADC_InjectedChannelConfig(ADC1, ADC_Channel_4, 4, ADC_SampleTime_41Cycles5);

    /* ADC1 injected external trigger configuration */
    ADC_ExternalTrigInjectedConvConfig(ADC1, ADC_ExternalTrigInjecConv_None);

    /* Enable injected external trigger conversion on ADC1 */
    ADC_ExternalTrigInjectedConvCmd(ADC1, ENABLE);

    /* Enable ADC1 */
    ADC_Cmd(ADC1, ENABLE);

    /* Enable ADC1 reset calibration register */
    ADC_ResetCalibration(ADC1);
    /* Check the end of ADC1 reset calibration register */
    while (ADC_GetResetCalibrationStatus(ADC1));

    /* Start ADC1 calibration */
    ADC_StartCalibration(ADC1);
    /* Check the end of ADC1 calibration */
    while (ADC_GetCalibrationStatus(ADC1));
}

/* configure the SysTick timer for correct period */
void InitSysTick()
{
    SysTick_Config(SystemCoreClock / SYSTICK_TIMER_FREQ);
}

/* SysTick interrupt handler - for Delay() function */
void SysTick_Handler(void)
{
    if (TimingDelay != 0x00)
    {
        TimingDelay--;
    }

}

/* simple Delay function, in SysTick increments */
void Delay(__IO uint32_t nTime)
{
    TimingDelay = nTime;
    while (TimingDelay != 0);
}

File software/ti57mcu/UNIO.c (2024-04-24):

/* Copyright (C) 2011 by Stephen Early <steve@greenend.org.uk>
Copyright (C) 2017 by Jeroen Lanting <https://github.com/NESFreak>

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
THE SOFTWARE IS PROVIDED "AS IS", WITHOUT WARRANTY OF ANY KIND,
EXPRESS OR IMPLIED, INCLUDING BUT NOT LIMITED TO THE WARRANTIES OF
MERCHANTABILITY, FITNESS FOR A PARTICULAR PURPOSE AND
NONINFRINGEMENT. IN NO EVENT SHALL THE AUTHORS OR COPYRIGHT HOLDERS BE
LIABLE FOR ANY CLAIM, DAMAGES OR OTHER LIABILITY, WHETHER IN AN ACTION
OF CONTRACT, TORT OR OTHERWISE, ARISING FROM, OUT OF OR IN CONNECTION
WITH THE SOFTWARE OR THE USE OR OTHER DEALINGS IN THE SOFTWARE.  */

#include "UNIO.h"

#include "stm32f10x.h"

/* GPT polled microsecond delay function */
void delayMicroseconds(uint16_t us)
{
    /* load the reload-register with target tick value */
    //TIM3->ARR = (us - 1);
    GPT_RELOAD(us - 1);

    /* force update of the PSC and ARR */
    //TIM3->EGR |= TIM_EGR_UG;
    GPT_UPDATE;

    /* start the timer */
    //TIM3->CR1  |= TIM_CR1_CEN;
    GPT_START;

    /* wait for timer to expire */
    while (TIM3->CR1 & TIM_CR1_CEN)
        __NOP();
}

/* GPT polled transition hunt function - returns true if transition found */
bool huntMicroseconds(uint16_t us)
{
    bool state;
    UNIO_HIGH;      // release bus to pullup

    /* load the reload-register with target tick value */
    //TIM3->ARR = (us - 1);
    GPT_RELOAD(us - 1);

    /* force update of the PSC and ARR */
    //TIM3->EGR |= TIM_EGR_UG;
    GPT_UPDATE;

    /* start the timer */
    //TIM3->CR1  |= TIM_CR1_CEN;
    GPT_START;

    /* capture the input state */
    state = !!(UNIO_INP);

    /* wait for timer to expire OR the state to change */
    while (GPT_RUNNING && (state == !!(UNIO_INP)))
        __NOP();

    /* stop the timer */
    //TIM3->CR1  &= ~TIM_CR1_CEN;
    GPT_STOP;

    /* return true if state changed */
    return (state == !(UNIO_INP));
}


static void unio_set_bus(bool state)
{
    if (state)
        UNIO_HIGH;
    else
        UNIO_LOW;
}

static inline bool unio_read_bus(void)
{
    return !!(UNIO_INP);
}

/* If multiple commands are to be issued to a device without a standby
   pulse in between, the bus must be held high for at least UNIO_TSS
   between the end of one command and the start of the next. */
static void unio_inter_command_gap(void)
{
    UNIO_HIGH;
    delayMicroseconds(UNIO_TSS_US + UNIO_MARGIN_US);
}

/* Send a standby pulse on the bus.  After power-on or brown-out
   reset, the device requires a low-to-high transition on the bus at
   the start of the standby pulse.  To be conservative, we take the
   bus low for UNIO_TSS, then high for UNIO_TSTBY. */
static void unio_standby_pulse(void)
{
    UNIO_LOW;
    delayMicroseconds(UNIO_TSS_US + UNIO_MARGIN_US);
    UNIO_HIGH;
    delayMicroseconds(UNIO_TSTBY_US + UNIO_MARGIN_US);
}

/* While bit-banging, all delays are expressed in terms of UNIO_BIT_US.
   We use the similar code path for reading and writing.  During a
   write, we perform dummy reads at 1/4 and 3/4 of the way through
   each bit time.  During a read we perform a dummy write at the start
   and 1/2 way through each bit time. By using a hardware General Purpose
   timer, this code is not NEARLY as critial as it would be if software
   loops were used. */

static bool unio_send_bit(bool w)
{
    bool a, b;
    unio_set_bus(!w);
    delayMicroseconds(UNIO_QUARTER_BIT_US);
    a = unio_read_bus();
    delayMicroseconds(UNIO_QUARTER_BIT_US);
    unio_set_bus(w);
    delayMicroseconds(UNIO_QUARTER_BIT_US);
    b = unio_read_bus();
    delayMicroseconds(UNIO_QUARTER_BIT_US);
    return b && !a;
}

static bool unio_receive_bit(void)
{
    bool a, b;
    unio_set_bus(1);  // release bus to pullup
    delayMicroseconds(UNIO_QUARTER_BIT_US);
    a = unio_read_bus();
    delayMicroseconds(UNIO_QUARTER_BIT_US);
    unio_set_bus(1);  // release bus to pullup
    delayMicroseconds(UNIO_QUARTER_BIT_US);
    b = unio_read_bus();
    delayMicroseconds(UNIO_QUARTER_BIT_US);
    return b && !a;
}
/* Send a single byte terminated by MAK/NoMAK. Return SAK/NoSAK status */
static bool unio_send_byte(uint8_t b, bool mak)
{
    for (int i = 0; i < 8; i++)
    {
        unio_send_bit(b & 0x80);
        b <<= 1;
    }
    unio_send_bit(mak);           // transmite MAK/NoMAK

    return unio_receive_bit();    // return SAK/NoSAK status
}

/* Receive a single byte terminated by MAK/NoMAK. Return SAK/NoSAK status */
static bool unio_receive_byte(uint8_t* b, bool mak)
{
    uint8_t data = 0;
    for (int i = 0; i < 8; i++)
    {
        data = (data << 1) | unio_receive_bit();
    }
    *b = data;
    unio_send_bit(mak);           // issue MAK/NoMAK

    return unio_receive_bit();    // return SAK/NoSAK status
}

/* Send multiple byte data on the bus. If end is true, send NoMAK after the last
   byte; otherwise send MAK. */
static bool unio_send_n_bytes(const uint8_t* data, uint16_t length, bool end)
{
    for (uint16_t i = 0; i < length; i++)
    {
        /* Rules for sending MAK: if it's the last byte and end is true,
           send NoMAK.  Otherwise send MAK. */
        if (!unio_send_byte(data[i], !(((i + 1) == length) && end)))
            return false;
    }
    return true;
}

/* Read data from the bus.  After reading 'length' bytes, send NoMAK to
   terminate the command. */
static bool unio_receive_n_bytes(uint8_t* data, uint16_t length)
{
    for (uint16_t i = 0; i < length; i++)
    {
        if (!unio_receive_byte(data + i, !((i + 1) == length)))
            return false;
    }
    return true;
}

/* Put the UNIO bus to sleep. This does NOT init the MCU GPT and GPIO
   resources! That must be done elsewhere. */
void UNIO_init()
{
    GPT_STOP;
    GPT_UPDATE;
    unio_standby_pulse();
}

/* Send a start header on the bus.  Hold the bus low for UNIO_THDR,
   then transmit UNIO_STARTHEADER.  There is a time slot for SAK after
   this transmission, but we must ignore the value because no slave
   devices will drive the bus; if there is more than one device
   connected then that could cause bus contention. */
static void unio_start_header(void)
{
    UNIO_LOW;
    //delayMicroseconds(UNIO_THDR_US + UNIO_MARGIN_US);
    delayMicroseconds(70);
    UNIO_HIGH;
    unio_send_byte(UNIO_STARTHEADER, true);
}

bool UNIO_read(uint8_t dev_address, uint8_t* buffer, uint16_t mem_address, uint16_t length)
{
    bool a, b;
    uint8_t cmd[4];
    cmd[0] = dev_address;
    cmd[1] = UNIO_EEPROM_READ;
    cmd[2] = (uint8_t)(mem_address >> 8);
    cmd[3] = (uint8_t)(mem_address & 0xff);
    unio_inter_command_gap();
    unio_start_header();
    a = unio_send_n_bytes(cmd, 4, false);
    b = unio_receive_n_bytes(buffer, length);
    return a && b;
}
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

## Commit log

2024-02-24 Initial commit
    fab01 KiCAD project
    rcl57console Pelles-C
    rcl57mcu Keil uVision
    [app_ti57.obj, current_calculations.xlsx, key57.obj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]
2024-02-24 HaD link, media files
    Updated readme with hackaday link, and added TI-57 image (from UK Computing History museum website) as well as 3D image from KiCAD fab01 release.
2024-02-28 checkin of V2 MCU board and V1 PSU/debug board
    these were split into two KiCad projects because the PSU and debug adapter only need 2 layers. Cleanup of KiCad projects, generation of PCB checkplots and schematic and assembly files.
    [rcl57_debug.kicad_sch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]
2024-03-11 debug level software
    most hardware specific items are in mux57.c file, as display and keyboard support is the bulk of the embedded hardware task. license file updated to include Jeff Parsons' original MIT as well as MIT 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
    [current_calculations.xlsx]
2024-03-15 EEPROM support & powersave
    Testing of power-save feature, and initial EEPROM driver implemented. Still not ready to run on real hardware yet.
2024-04-24 working on TI55 donor board
    ADC key column read, UNIO EEPROM read/init, power-save mode. Assumes V2 PCB with 2K pulldowns on K1-K5 inputs.
    Updated schematic and PCB to "v3" to include the pulldown pack and simplify power options. V3 board not yet sent out for fabrication.
    [app_ti57.obj, key57.obj, leds57.obj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]
2024-05-14 3D printed lid added
    version 1.3 of the 3D printed lid fits nicely into my TI-55 and TI-57 calculators. Design tool is OpenSCAD, so it would be easy to modify for other PCB e.g. one that makes 9V output for unmodified ca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
    [TI-57_LiPo_lid_1v3.scad, TI-57_LiPo_lid_1v3.stl]
